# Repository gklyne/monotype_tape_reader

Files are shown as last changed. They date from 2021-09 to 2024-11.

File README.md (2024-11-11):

# monotype_tape_reader

Mechanical parts for reading paper tape created by Monotype keyboard.

To run the tape reader, plug the reader RPi in to the Mac USB port (middle port on RPi, not "Pwr in"), allow it a few seconds to start up, then SSH to the RPi:
    ssh graham@192.168.1.23  (p:a...?)
or:
    ssh graham@mcreader.local

(Before first time, from a Macbook, add an "RNDIS/Ethernet gadget" interface with DHCP network config, and no network address hiding.  This should then find the reader Raspberry Pi using mDNS (Bonjour).  Don't forget to turn off "Limit IP address tracking".  Thnen log in using "mcreader.local" option above.)

Once logged in, seek out and run `stepper-control.py`.

## TODO

### 2021-09-27: Revisions to first prototype

- [x] Stiffen camera support area of baseplate so it doesn't flex with weight of phone.  Propose to extend plate both sides of reader bar.

- [x] Camera support bracket:  make space for nuts on the threaded rod (move holes away from vertical side)

- [x] Camera support bracket: increase width of base.

- [x] positive location/keying for reader bar.

- [x] Increase M4 hole size

- [x] Arrangement to prevent phone holder rotating on bar.  Also improve phone positioning.

- [x] Countersink for winder crank screw; review crank design to ensure pulley groove is clear of turning crank

- [x] Option to remove winder so that tape can be loaded/unloaded.

- [x] tape tensioning arrangement.  Guides to wrap tape around reader bar?

- [x] slot in winder shaft for catching tape (?)  C-clip over shaft?

- [x] Clamp to attach reader mechanism to a solid baseplate.

- [x] Larger gaps and guide rods for reader bar

### 2022-08-19: revisions to Mk2

(see Journal/20220819-MC-journal-reader-mk2.md)

[x] Redesign the tape-path guides to use guide sprockets.

[x] Include a small raised inner hub on the support brackets for the tape spools.

[x] Make the tape spools wider (more excess over width of the tape)

[x] Use a spoked design for the tape spools (less plastic, print time and weight).

[x] Replace axle for tape spools with a plastic locking arrangement, so they are more easily separated to remove the tape.

[x] Redesign the tape clips to slip on and off the winder spools, and with a lip to stop them spinning

### 2022-10-02: revisions to Mk2.5

[x] Clip wider flange

[x] Storage clip more clearance, no break.  This to allow it to slide off.

[-] Stiffer baseplate (8 -> 12mm edge height?) (doesn't seem necessary?)

[x] Additional mount and foot for winder/stepper (front edge)

[x] Winder separate from reader bridge (drive belt stresses structure)

[x] Captive nut holders in baseplate (shortened overall length by 100cm)

[-] Make the baseplate wider (doesn't seem necessary?)

[x] Sprocket pins larger (why are they so small?)

### 2022-12-10: using stepper motor to driver spool

[x] Code options for stop, start, speed?

[x] Stiffen up stepper motor bracket and spool support

[x] Single piece side support and stepper bracket

[x] Larger stepper pulley for drive

[x] Sprocket guides wrap further around sprockets

### 2023-02-03: tweak design

[x] smaller stepper motor pulley (50mm -> 35mm) - should be less liable to stalling motor

[x] wider flanges on tape guide rollers, reduced tape width clearance - hopefully reducing tendency of tape to ride up on rollers.

[x] adjust to use nylock nuts for axle supports, to prevent the axles from tightening on the supports while processing a tape.

[x] increase height of guide sprocket pins, to try and reduce tendency for the tape to ride off the pins

[x] redesign spool clip

## 2023-02-16: reasonably successful recording (?)

[x] Try spool clip without support bridges

[x] Drive belt channel should be wider, U-profile.

[x] Balance feeder spool (handle makes it unbalanced)

[x] Shim for spool end, for more positive "click"

## 2023-02-20:

[x] Smaller stepper motor pulley

[x] Reader bridge add shades to reduce detection of outer EL wire

[x] Use dark colour plastic for reader bridge

[x] Redesign winder spools to use smaller shaft dia; 
    e.g. M4 using bolts rather than through-rod.
    This is to reduce friction when drawing the tape off the spool.

[x] Design arms to hold tape tensioner(s)

[x] Slow down default tape speed (2.5ms -> 3ms between steps)

[x] Check ordering of row data when multiple detected together

[x] Add video frame number to output data file

## 2023-02-20:

[x] Progressive slowing of stepper motor as reading proceeds.

## 2023-09-24:

Following [meeting with Dawn](Journal/20230924-more-reader-changes-needed.md).

[x] Wider slot for brighter EL wire (+0.2mm)

[x] Wider light baffles on EL bridge

[x] Drive belt tensioning arrangement

[x] More flexibility of camera positioning

[x] Make camera clamp screws easier to access

[x] Mount for Pi Zero and EL switch wire (and power supplies?)

## 2023-11-25

[x] Winder side clip not closed

[x] Hinge on motor mount is too close

[x] Extend curved slot towards motor body

[x] Extend tension adjustment link by 2-3mm

[x] Shorten & widen tension adjustment clamp/nut holder

[x] Reduce size of screw bulge on motor holder (radius by 1mm?)

[x] Wider spacer ridge on inside of winder holder side

## 2023-12-01

[x] Extend arm on winder holder side; shorten adjustment link.
    - still need to choose adjustment arm length
    - is this a good idea? Single link may be more rigid

[x] Adjuster link countersink one end only.  Other end uses cap head.

[x] Lower baffle (shade) on reader bridge

[x] Winder spool axis: use bearing or sleeving to avoid creep along the shaft thread
    - use spool design from free end, and add sleeves over M4 screw.
    - New clip holes need to be diameter of sleeve.
    - Use sleeve bearings on both spools to reduce drag.

[x] Shorter roller arm on take-up spool side?

[x] Small collection of tools to facilitate assembly/maintenance

## 2024-01-13

[x] Iterations on design of tape follower roller arm, to allow free movement of the tape

## 2024-02-21

[x] Increase overhang of bridge shade shells (+1mm inside and outside)

[x] Revert to smaller EL wire and smaller gap in bridge

[x] Redesign reader device to be more uniform with less wobble

[ ] 

## 2024-06-28

[x] Design tweaks while reprinting with PETG, following "meltdown" of original PLA print.  (Turns out the PLA can start sagging when left out in the sun.)

[x] Widen baseplate by 2mm to provide more clearance for the rollers/spools.

## To consider (2024-02-13)

[ ] Threshold detection coordinate extraction is a bottleneck -- can this be optimized?
    - see function 'find_frame_regions'
    - possible to detect and merge local overlaps before comparing all?
    - Or collapse row-runs of pixels into (min,max) groupings?

[ ] Shorter EL wire? 

[ ] Provide "output_log.txt" file to analyse algorithm behaviour details
    - region detection: num regions, region size, shape variations
    - trace detection: summarize contributing regions
    - row detection: initial and final candidates

[ ] Marker threshold setting is rather sensitive

[ ] Analyze threshold setting w.r.t. region area and shape variations; also number of regions detected.  Can threshold setting be adjusted automatically using this?   (See logging options above.)

## Shelved

[ ] Running calibration of data scale - maybe it's not truly linear (consistent hole 22 deviation).
    Consider low order polynomial, correction (quadratic?, cubic?)

[ ] Use battery supply for EL wire (less prone to brightness changes?)

[ ] Attach battery supply to reader rig

## Notes

### Notes: 2023-03-05

## Write-up notes

### Pipeline

Iterating the design

Aim to use software as much as possible, while keeping the hardware simple

Design involving iterative updates to both hardware and software

Initially: reader and video analysis

Then switch to 3 elements: hardware, stepper control s/w, video analysis

Basic mechanism and analysis worked fairly easily, but...

Dealing with noisy data, interactions between:
- better video analysis
- better hardware
- better tape motion control

Lots of learning:  more efficient use of OpenSCAD for evolving mechanical design; OpenCV for video analysis and generation, Raspberry Pi to control stepper motor, simple statistics-based algorithms for dealing with noisy data.

Each attempt to improve the decoding software can show up fundamental problems with the raw data, which are not reliably overcome by better processing (e.g. might confuse a human attempting to decode the data), thus giving rise to new hardware iterations.  Then each new hardware iteration and video recording can throw up new patterns of data noise to be handled by the decoding software, so there's a lot of iteration between hardware and software improvements.

Ambient lighting is a big factor in the quality of video obtained.

### Reader hardware

Initially simple hand crank from  spool to spool, drawing tape over EL wire

Tape guide hardware enhancements to reduce tape wear

Hardware enhancements to use less plastic when printing

Using code to describe hardware (CSG, OpenSCAD)

Building a component library (OpenSCAD)

Increase spool size to reduce tape speed variation beginning to end (pre-stepper)

Switched to stepper motor drive for better control of tape speed

Additional hardware (RPi, stepper controller, stepper motor) and software to control stepper

Added speed profile (to control software) as analysis had holes merging towards end of tape

Add tape follower rollers to help keep tape on guide sprockets, and absorb some slack

Add rod mounting plate extensions to leave for space for tape follower roller arms

Add drive belt tensioner to control slippage

Use smaller shafts and metal sleeve bearings for smoother tape movement

Experiment with wider, brighter EL wire, but this ended up with rows getting merged

Extra hardware for mounting RPi, and other bits, on reader frame

### Decoding software

Processing pipeline

Uses OpenCV to read recorded video, and to perform initial threshold detection

Initial processing draws inspiration from motion capture software implemented in 1980s

Pipeline applies conversion from (X,Y) coordinates in video to (Y,frame) coordinates for data decode.

Row detection uses RANSAC-inspired algorithm to identify row-aligned markers.

Also uses OpenCV to create synthesized video of analysis process, with original video and internal data from processing pipeline.

Data visualization has proved very important whole developing algorithm, especially for understanding the impact of noisy data and helping to identify algorithmic improvements.  Also helped to identify where hardware improvements were needed.

Have spent significant thought reflecting on how I, as a human observer, am easily seeing row data where the algorithm if failing.  This has led to changes in the structure of the pipeline; e.g. noticing that the sprocket holes are a very regular pattern, and introducing in-pipeline feedback to use detected sprocket holes to help discard spurious data in the earlier row-detection phase.

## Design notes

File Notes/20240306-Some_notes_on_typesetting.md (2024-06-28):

# Some_notes_on_typesetting.md

Some notes on the typesetting process

Clarice's diary was hand written in an exercise book during the period 1915-16.  This printed version has been produced using the Monotype system, the process for typesetting that would have been used in her lifetime.

The Monotype system consists of two machines: a keyboard and a caster which communicate by means of a spool of punched paper tape.  The keyboard produces the spool containing encoded text and layout information.  The caster reads the punched code and, line by line, produces pages of justified type cast from molten lead using a matrix.  The chosen typeface, in this case Bulmer 11pt, is determined by the matrix containing a grid of character moulds.

This entirely mechanical system revolutionised book production during the early 20th century.
The use of punched paper tape was an idea ahead of its time, which reappeared later in digital computers.
It was offset and digitised production processes built around these computers that were to eventually replace the Monotype system in the latter half of the century.

Monotype is a rare system that is now hard to find in use.  Stan Lane of Gloucester Typesetting Services has been using this process for over 40 years, and is now passing the mantle to Katie Beard of Rooksmoor Press.  Their knowledge and expertise are what has made production of this book possible.

....

_Dawn Cole is the keeper of the Clarice Alberta Spratling archive, and has been using its contents as inspiration for her creative practice as a conceptual artist since 2007._

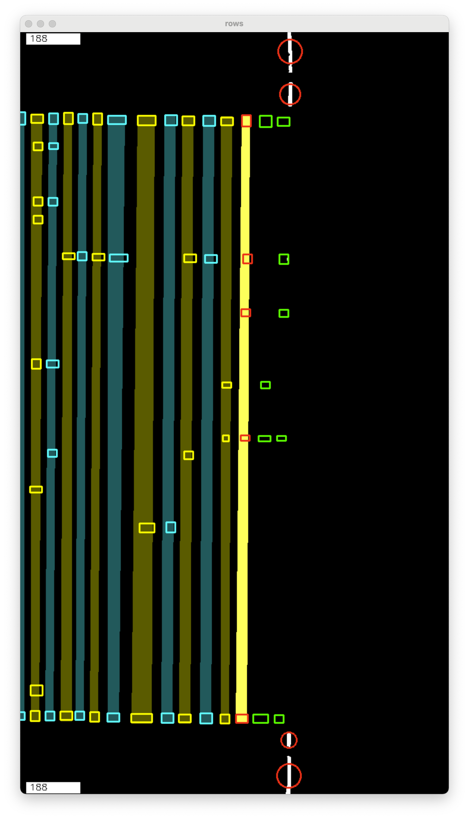
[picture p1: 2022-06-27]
Notes/DHOxSS-poster/20220523-MC-rows.png

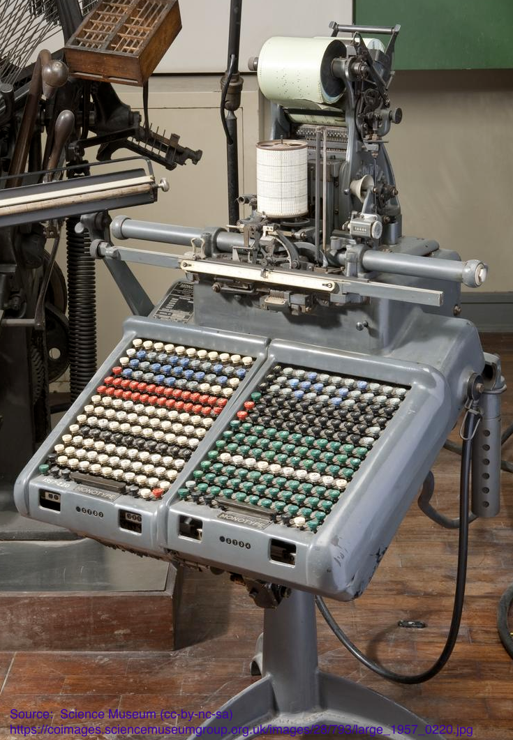
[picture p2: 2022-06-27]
Notes/DHOxSS-poster/20220519-monotype-keyboard.png

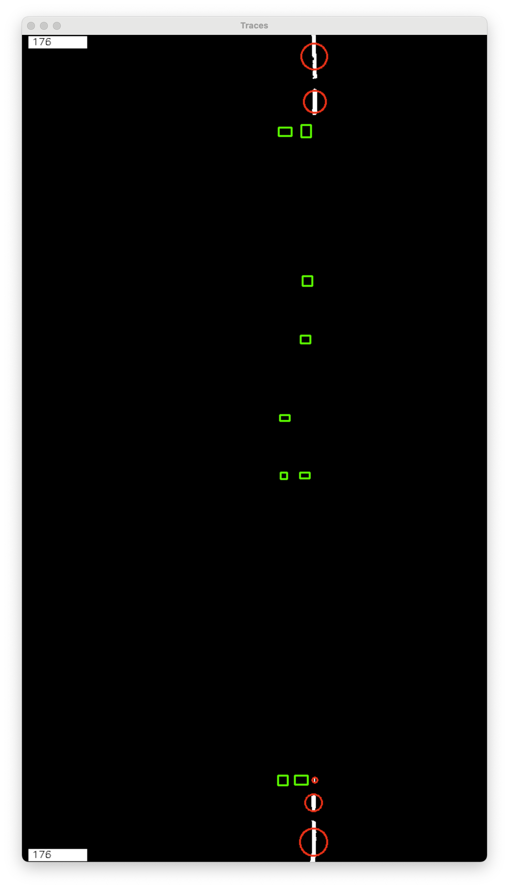
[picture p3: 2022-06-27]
Notes/DHOxSS-poster/20220523-MC-traces.png

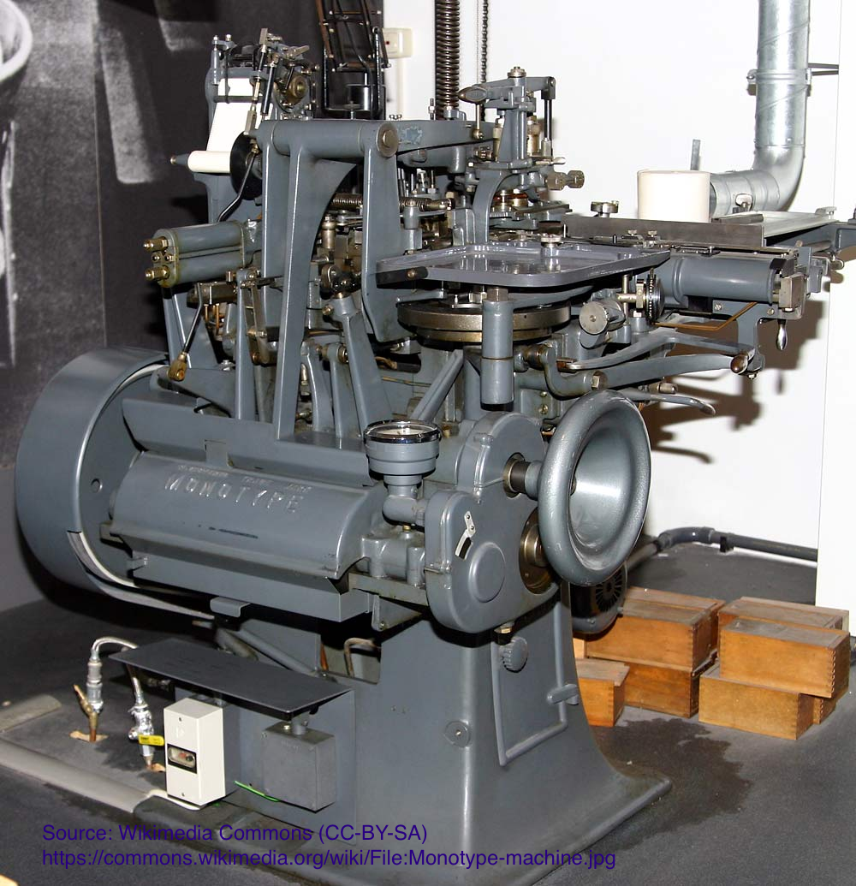
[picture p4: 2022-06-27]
Notes/DHOxSS-poster/20220519-monotype-caster.png

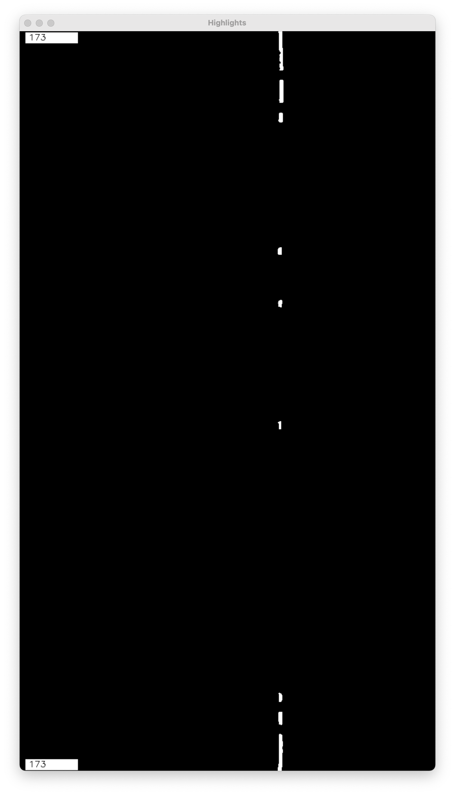
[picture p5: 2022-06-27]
Notes/DHOxSS-poster/20220523-MC-highlights.png

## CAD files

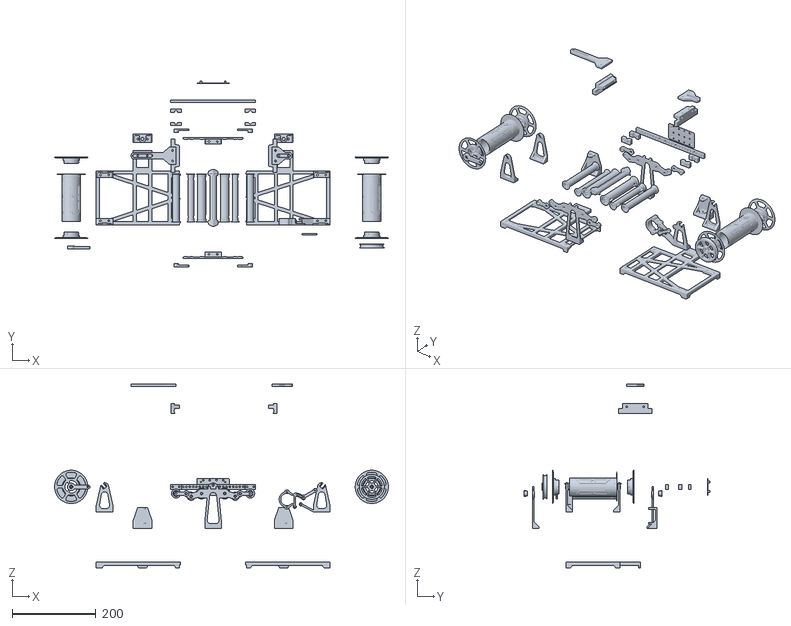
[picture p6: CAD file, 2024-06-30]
Monocaster-assembly-exploded.stl
800.0 x 444.5 x 440.0

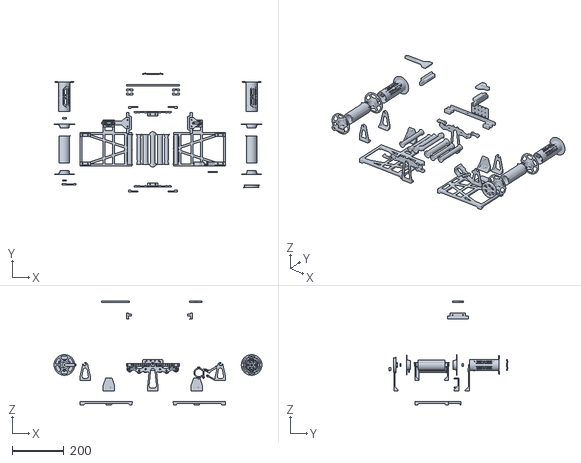
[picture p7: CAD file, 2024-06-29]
Monocaster-assembly.stl
800.0 x 459.5 x 400.0

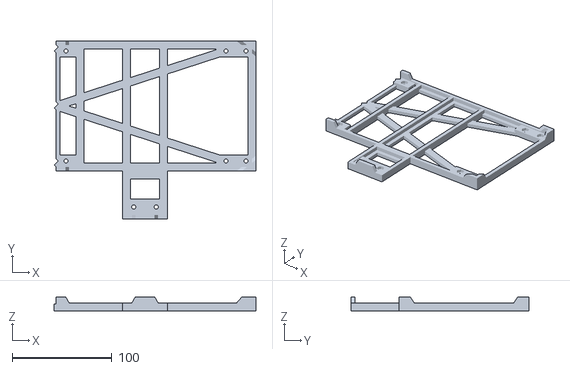
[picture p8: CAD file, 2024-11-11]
stl/reader_half_baseplate_2.stl
202.0 x 178.0 x 14.0

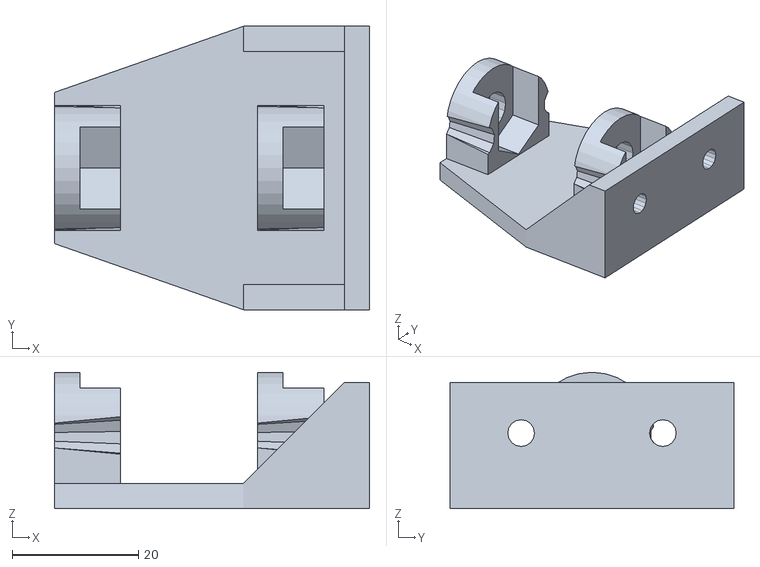
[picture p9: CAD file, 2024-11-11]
stl/phone_holder_rod_support.stl
50.0 x 45.0 x 21.6

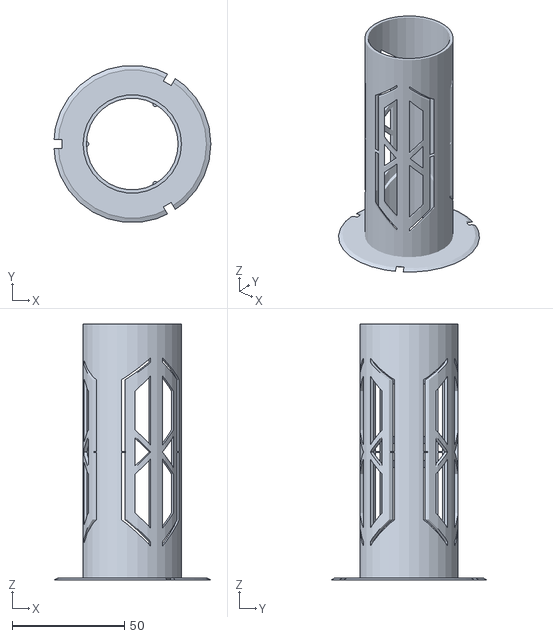
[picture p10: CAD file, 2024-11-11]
stl/spool_clip_closed.stl
69.8 x 69.6 x 113.9

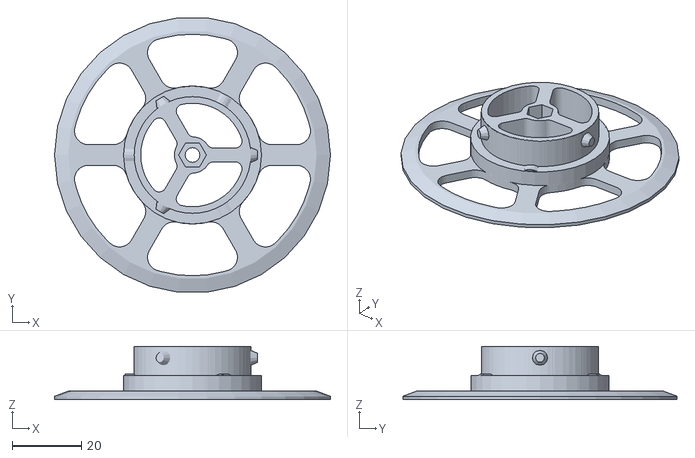
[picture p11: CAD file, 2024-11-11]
stl/spool_end.stl
80.0 x 79.6 x 15.5

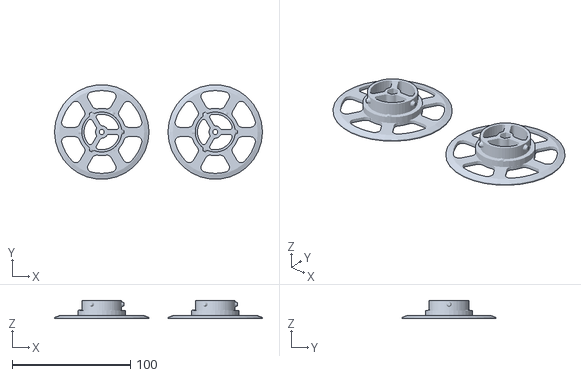
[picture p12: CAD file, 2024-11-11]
stl/spool_end-2off.stl
176.0 x 79.6 x 15.5

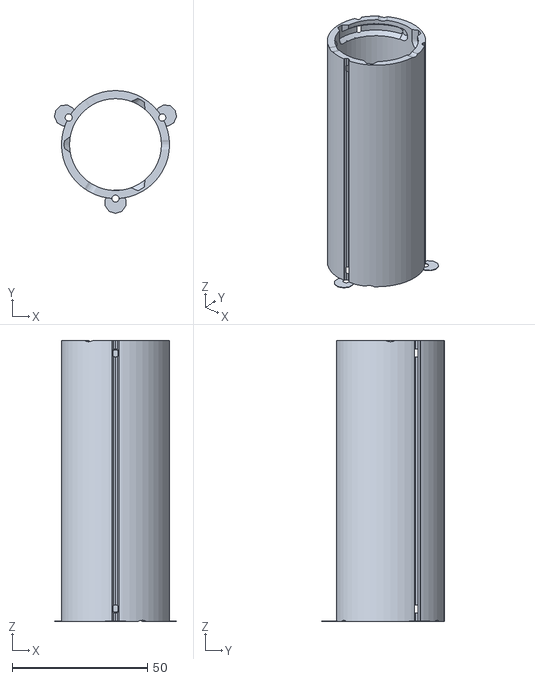
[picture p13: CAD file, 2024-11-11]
stl/spool_middle.stl
45.2 x 45.5 x 104.0

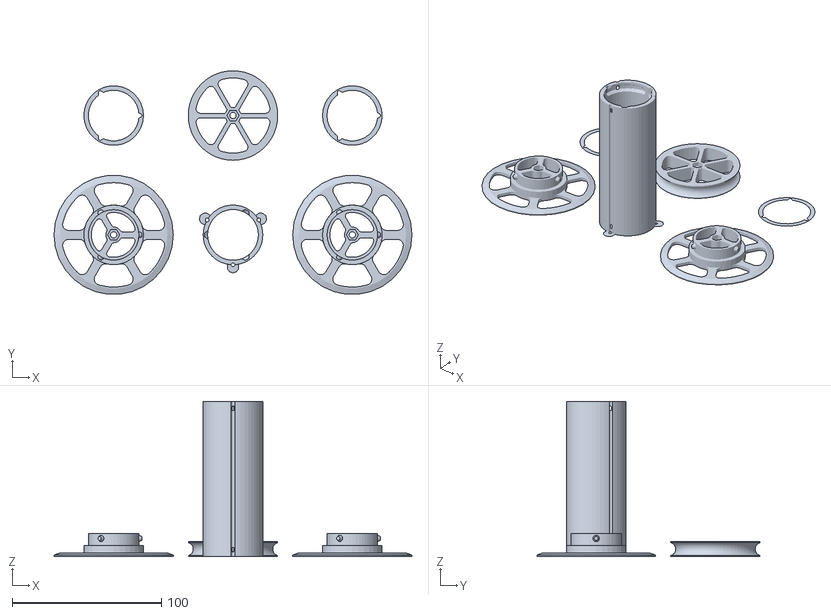
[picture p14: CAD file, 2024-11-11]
stl/spool_all_parts.stl
240.0 x 149.8 x 104.0

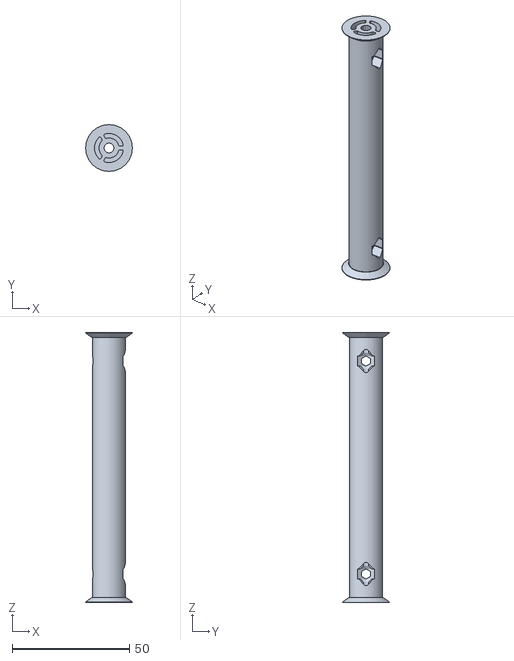
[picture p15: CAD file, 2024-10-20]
stl/roller_tape_guide.stl
20.0 x 20.0 x 115.0

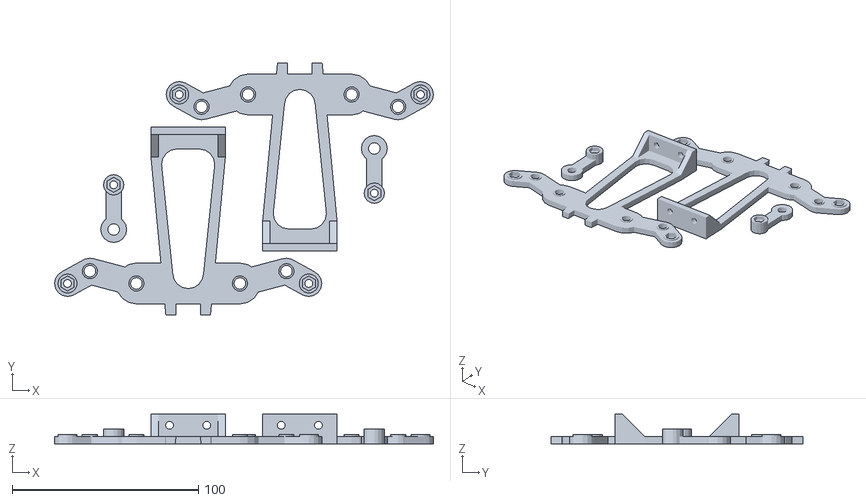
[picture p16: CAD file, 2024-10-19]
stl/reader-bridge-side-supports-and-follower-arms.stl
203.6 x 135.5 x 16.0

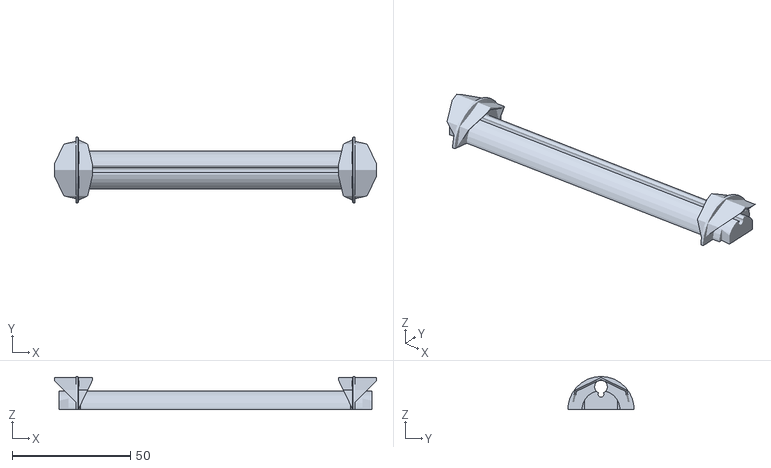
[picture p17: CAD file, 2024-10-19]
stl/tape_reader_bridge_dovetailed.stl
136.0 x 27.8 x 14.0

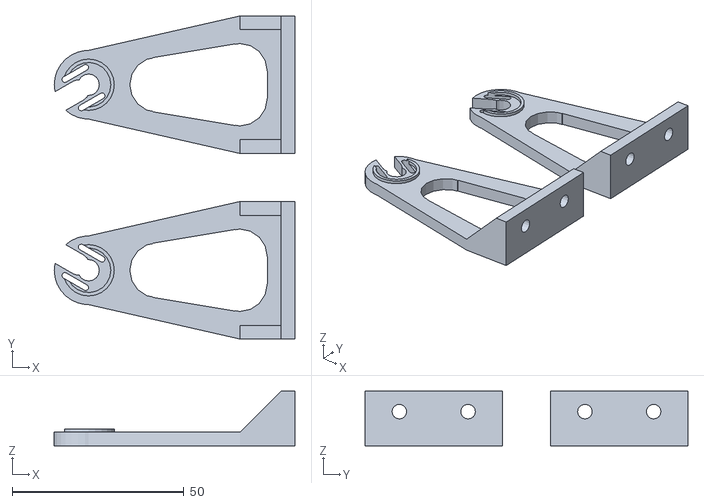
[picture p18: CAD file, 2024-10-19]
stl/spool_side_support_slotted-2off.stl
70.0 x 94.0 x 16.0

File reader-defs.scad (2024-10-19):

// Default dimensions

m_clearance = 0.25 ;        // Clearance for close-clearance holes
m2_5    = 2.5+m_clearance ; // Close clearance hole for M2.5 screw
m3      = 3+m_clearance ;   // Close clearance hole for M3 screw
m4      = 4+m_clearance ;   // Close clearance hole for M4 screw
m5      = 5+m_clearance ;   // Close clearance hole for M5 screw
m6      = 6+m_clearance ;   // Close clearance hole for M6 screw/sleeve
m8      = 8+m_clearance ;   // Close clearance hole for M8 screw/sleeve

m2_5_nut_af = 5.0 ;         // M2.5 nut a/f size
m2_5_nut_t  = 2.0 ;         // M2.5 nut thickness (for recess)
m2_5_csink  = m2_5*2 ;      // M2.5 countersink diameter

m3_nut_af    = 5.5 ;        // M3 nut a/f size
m3_nut_t     = 2.2 ;        // M3 nut thickness (for recess)
m3_hinge_dia = 8.0 ;        // M3 hinge knuckle diameter
m3_csink     = m3*2 ;       // M3 countersink diameter

m4_nut_af    = 7 ;          // M4 nut a/f size
m4_nut_t     = 3.1 ;        // M4 nut thickness (for recess)
m4_slimnut_t = 2.5 ;        // M4 slim nut thickness (for recess)
m4_nylock_t  = 4.3 ;        // M4 nylock nut thickness (for recess)
m4_csink     = m4*2 ;       // M4 countersink diameter
m4_washer_d  = 8.9 ;        // M4 washer diameter
m4_washer_t  = 0.9 ;        // M4 washer thickness

m8_nut_af    = 13 ;         // M8 nut a/f size
m8_nut_t     = 6.5 ;        // M8 nut thickness (for recess)
m8_slimnut_t = 4 ;          // M8 slim nut thickness (for recess)

// Monotype system parameters

// 159/50 = 3.18
// 285.5/90 = 3.172
mt_sprocket_pitch = 3.2 ;   // was: 159/50; paper was riding up on pins after about 20 holes
mt_sprocket_dia   = 1.6 ;   // was: 1.5
mt_sprocket_width = 104.3 ; // Between sprocket hole rows
mt_overall_width  = 110 ;   // Overall width of tape
mt_paper_tickness = 0.08 ;  // Thickness of paper tape

// Winder

small_shaft_d      = m4 ;           // Shaft diameter
small_shaft_nut_af = m4_nut_af ;    // Nut diameter across faces
small_shaft_nut_t  = m4_nut_t ;     // Nut thickness

// Spool shaft may be used with a sleeve to make up to "shaft_d"
spool_shaft_d      = m4 ;           // Shaft diameter in spool
spool_shaft_nut_af = m4_nut_af ;    // Nut diameter across faces
spool_shaft_nut_t  = m4_nut_t ;     // Nut thickness
spool_sleeve_d     = m6 ;           // Spool sleeve bearing diameter

// shaft_d      = small_shaft_d ;
// shaft_nut_af = small_shaft_nut_af ;
// shaft_nut_t  = small_shaft_nut_t ;

shaft_d      = m8 ;                 // Shaft diameter in carrier
shaft_nut_af = m8_nut_af ;          // Nut diameter across faces
shaft_nut_t  = m8_slimnut_t ;       // Nut thickness

// Spool dimensions
core_d = 40 ;           // Core diameter
bevel_d = 72 ;          // Bevel inner diameter
outer_d = 80 ;          // Spool outer diameter
crank_hub_d = 25 ;      // Diameter of crank hub
drive_pulley_d = 60 ;   // Diameter of drive pulley
drive_pulley_t = 10 ;   // Thickness of drive pulley
handle_hub_d = 10 ;     // Diameter of handle end of crank
handle_d = m4 ;         // Diameter of handle
base_fix_d = m4 ;       // Diameter of base fixing screw hole
sup_t = 4 ;             // Default thickness for side supports @@was side_t

crank_l = 40 ;          // Length of crank (between shaft and handle centres

crank_hub_t = 16 ;      // Thickness of crank hub
crank_arm_t = 6 ;       // Thickness of crank arm
crank_end_t = 8 ;       // Thickness of crank handle hub (at end of arm)

spool_side_t = 2.5 ;    // Thickness of carrier spool side
spool_side_rim_t = 1 ;  // Thickness of carrier spool side rim (bevelled)
spool_w_all = 114 ;     // Width of spool (overall between ends)
                        // base_w - 2*(read_side_t+read_extra_l) ;
spool_w_end = 5 ;       // Width of spool (to inside of end)
spool_w_plug = 8 ;      // Width of spool-end plug overlap
spool_w_mid = spool_w_all - 2*spool_w_end ;
                        // width of spool middle spacer


handle_nut_af = 7 ;     // Nut diameter across faces
handle_nut_t  = 3 ;     // Nut thickness

winder_side_h = 60 ;    // Height to centre of winder shaft
winder_side_w = 40 ;    // Width base of winder side support
winder_side_t = sup_t ; // Thickness of winder side support
winder_apex_d = 20 ;    // Diameter of apex of winder side support
winder_base_t = 16 ;    // Thickness at base of winder

motor_support_l = 35 ;  // Length of motor mount support arm
motor_support_a = 20 ;  // Angle of motor mount support arm
motor_swivel_l  = 35 ;  // Length of motor swivel link (to clear spool rim)

// Reader bridge

read_w = 16 ;           // Width of bridge
read_extra_l = 5 ;      // Extra length of reader bridge for guides and tie-down

read_h = 95 ;           // Height of reader bridge above base plate
read_side_t = sup_t ;   // Reader bridge side support thickness
read_side_base_t = 16 ; // Reader bridge side support thickness at base 
read_total_l     = spool_w_all + 2*(read_side_t + read_extra_l) ;
read_side_apex_w = 24 ;
read_side_apex_h = 6 ;  // Height of dovetail on sides
read_side_base_w = 40 ;
read_side_peg_d  = m4 ;

// See: module tape_reader_bridge_with_guides
read_groove_w = 2.5 ;    // EL wire groove width
                         // (bright wire is 2.6 dia; use ???)
                         // (regular wire is 2.25-2.3 dia;  use 2.5)

guide_w  = 28 ;         // Width of guide flange on bridge
guide_tc = 2 ;          // Guide thickness at core
guide_tr = 1 ;          // Guide thickness at rim
guide_tb = guide_tc-guide_tr ;  // Guide thickness of bevel
guide_eld = 5.5 ;       // EL wire threading hole diameter
guide_ist = 5 ;         // EL wire shade inner overhang thickness
guide_ost = (read_total_l-spool_w_all)/2+2 ; // EL wire shade outer overhang thickness

// Guide roller parameters (shape of rims each end)

guide_rim_1_extra_radius = 3 ;      // Rim bevel outer 
guide_rim_2_extra_radius = 0.25 ;   // Rim bevel inner
guide_rim_1_width        = 0.2 ;    // Rim end thickness
guide_rim_2_width        = 2 ;      // Rim bevel thickness 
guide_rim_overall_width  = mt_overall_width + 5 ;  // Each rim 2.2 + 0.6 tape clearance

// Guide sprocket diameter and positioning...
guide_sprocket_dia      = 22 ;
guide_sprocket_sep      = guide_sprocket_dia*1.8 + read_w ;
guide_sprocket_ht_off   = guide_sprocket_dia*0.5 ;

// Guide roller diameter and positioning...
guide_roller_outer_d        = 14 ;
guide_roller_centre_x       = guide_sprocket_ht_off*1.6 ;   // e.g. 1.6 for droop, 
                                                            // 1 for level, 0.7 for lift
guide_roller_centre_y       = 
    guide_sprocket_sep/2 + 
    guide_sprocket_dia*0.5 + guide_roller_outer_d*0.5 + 
    guide_rim_1_extra_radius*2 + 1 ;

// Guide follower positioning
guide_follower_pivot_x      = guide_sprocket_ht_off*1 ;     // e.g. 1.6 for droop, 
                                                            // 1 for level, 0.7 for lift
guide_follower_pivot_y      = guide_roller_centre_y + 12 ;

tape_follower_arm_l         = 40 ;          // Arm length between shaft centres
tape_follower_short_arm_l   = 24 ;          // Short arm length between shaft centres
tape_follower_elbow_l       = 10 ;          // Length from pivot to end of elbow


// Parts for holding phone camera

hold_side_l = 80 ;      // Length is side of holder
hold_side_h = 12 ;      // Height of side above base
hold_side_t1 = 8 ;      // Thickness of side at base
hold_side_t2 = 10 ;     // Thickness of side at top

hold_base_l1 = 60 ;     // Length of base near side
hold_base_l2 = 50 ;     // Length of base towards centre
hold_base_t = 8 ;       // Thickness of base (to accommodate hole)
hold_base_w = 20 ;      // Width of base piece
hold_base_offset = 4 ;  // Thickness of standoff for clamp nut clearance

hold_rail_p = 40 ;      // Distance between rail holes
hold_rail_d = m4 ;      // Diameter of rail holes

hold_fix_p   = 25 ;     // Distance between fixing holes
hold_fix_d   = m4 ;     // Diameter of fixing holes
hold_nut_t   = 3.1 ;    // Thickness of holder fixing nut
hold_nut_af  = 6.9 ;    // Size across faces of holder fixing nut recess (tight fit)
hold_fix_o_x = 20 ;     // X-offset from vertical rod to holder fixing holes
hold_fix_o_y = 0 ;      // Y-offset from vertical rod to centre between fixing holes

// Dimensions for phone holder-to-rod attachment plate

hold_fix_t = 6 ;        // Thickness of plate (Z)
hold_fix_w = 8 ;        // Width of plate to shoulder (X)
hold_fix_l = 80 ;       // Length of phone holder-to-rod fixing (Y)
hold_fix_rod_d = m8 ;   // Diameter of phone holder support rod
hold_fix_hub_d = 16 ;   // Diameter of phone holder support hub

hold_fix_plate_l = hold_fix_o_x + hold_fix_rod_d ;
hold_fix_plate_w = hold_fix_p + hold_fix_rod_d*2 ;

// Dimensions for long slot plate to prevent rotation of camera

hold_slot_o_x1 = 60 ;   // Start of anti-rotation slot
hold_slot_o_x2 = 100 ;  // end of anti-rotation slot

// Dimensions for short slot plate to allow sideways adjustment of camera
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

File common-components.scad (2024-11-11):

////////////////////////////////////////////////////////////////////////////////
// Common components
////////////////////////////////////////////////////////////////////////////////

delta = 0.01 ;
clearance = 0.1 ;

module triangle_plate(x1,y1,x2,y2,x3,y3,h) {
    // Trangular plate on X-Y plane
    //
    // x1 = X position of first apex
    // y1 = Y position of first apex
    // x2 = X position of second apex
    // y2 = Y position of second apex
    // x3 = X position of third apex
    // y3 = Y position of third apex
    // h  = height (thickness) of plate
    linear_extrude(height=h, center=false) {
        polygon(
            points=[
                [x1,y1],
                [x2,y2],
                [x3,y3],
                [x1,y1],
                ]
            ) ;
    }
}
////-triangle_plate(x1,y1,x2,y2,x3,y3,h) instance
// triangle_plate(-10,-10,-10,+10,10,5,5) ;

module rectangle_plate(x1,y1,x2,y2,h, scale=1) {
    // Rectangular plate on X-Y plane
    //
    // x1 = X position of first apex
    // y1 = Y position of first apex
    // x2 = X position of opposite apex
    // y2 = Y position of opposite apex
    // h  = height (thickness) of plate
    // scale = reduces X-Y coordinates towards top of plate (see linear_extrude)
    //
    linear_extrude(height=h, center=false, scale=scale) {
        polygon(
            points=[
                [x1,y1],
                [x2,y1],
                [x2,y2],
                [x1,y2],
                [x1,y1],
                ]
            ) ;
    }
}
////-rectangle_plate(x1,y1,x2,y2,h, scale=1) instance
// rectangle_plate(-10,-10,10,15,5) ;
// rectangle_plate(10,15,20,30,5, scale=0.5) ;

module lozenge(l,bevel_l,w,h) {
    // Lozenge object along Z axis: one point on origin, other on X-axis
    //
    // l       = overall length (between points)
    // bevel_l = length of sloping shoulder
    // w       = width of lozenge
    // h       = height of lozenge
    //
    linear_extrude(height=h, center=false) {
        polygon(
            points=[
                [0,        0],  
                [bevel_l,  w/2],
                [l-bevel_l,w/2],
                [l,        0],
                [l-bevel_l,-w/2],
                [bevel_l,  -w/2],
                ]
            ) ;
    }
}

module oval(x, d, h) {
    // Oval shape aligned on the X axis, with one end centred on the origin
    //
    // x  = X position of second centre of curvature
    // d  = width of oval, also diameter of curved ends
    // h  = height (thickness) of oval
    //
    cylinder(d=d, h=h, $fn=16) ;
    translate([x,0,0])
        cylinder(d=d, h=h, $fn=16) ;
    translate([x/2,0,h/2])
        cube(size=[x, d, h], center=true) ;
}

module oval_xy(x1, y1, x2, y2, d, h) {
    // Oval shape on the X-Y plane, with ends at the indicated positions
    //
    // x1 = X position of first centre of curvature
    // y1 = Y position of first centre of curvature
    // x2 = X position of second centre of curvature
    // y2 = Y position of second centre of curvature
    // d  = width of oval, also diameter of curved ends
    // h  = height (thickness) of oval
    //
    l = sqrt((x2-x1)^2+(y2-y1)^2) ;     // Length of oval (between radius centres)
    a = atan2(y2-y1,x2-x1) ;            // Angle of oval from X-axis
    translate([x1,y1,0]) {
        cylinder(d=d, h=h, $fn=16) ;
        rotate([0,0,a])
            translate([0,-d/2,0])
                cube(size=[l, d, h], center=false) ;
    }
    translate([x2,y2,0])
        cylinder(d=d, h=h, $fn=16) ;
}
////-oval_xy(x1, y1, x2, y2, d, h) instance
// oval_xy(-20,30,-60,-60,10,5) ;


module hub(d, h) {
    // Hub: cylinder with hole for fixing, on X-Y plane, centred on the origin
    //
    // d  = diameter of fixing hole
    // h  = height (thickness) of hub
    //
    difference() {
        cylinder(d=d*1.6, h=h, $fn=16) ;
        shaft_hole(d, h) ;
    }
}

module brace_xy(x1, y1, x2, y2, w, d1, d2, h) {
    // Brace with rounded ends with fixing holes
    //
    // x1 = X position of first fixing hole
    // y1 = Y position of first fixing hole
    // x2 = X position of second fixing hole
    // y2 = Y position of second fixing hole
    // w  = width of brace
    // d1 = diameter of fixing hubs
    // d2 = diameter of fixing holes
    // h  = height (thickness) of brace
    //
    l = sqrt((x2-x1)^2+(y2-y1)^2) ;     // Length of brace (between radius centres)
    a = atan2(y2-y1,x2-x1) ;            // Angle of brace from X-axis
    difference() {
        union() {
            translate([x1,y1,0]) {
                cylinder(d=d1, h=h, $fn=16) ;
                rotate([0,0,a])
                    translate([0,-w/2,0])
                        cube(size=[l, w, h], center=false) ;
            }
            translate([x2,y2,0])
                cylinder(d=d1, h=h, $fn=16) ;
        }
        translate([x1,y1,0]) shaft_hole(d2, h) ;
        translate([x2,y2,0]) shaft_hole(d2, h) ;
    }
}
////-brace_xy(x1, y1, x2, y2, w, d1, d2, h) instance
// brace_xy(-20,30,-60,-60,8,12,8,5) ;


module shaft_hole(d, l) {
    // Cutout for shaft hole diameter d and length l
    // Shaft axis on Z axis.
    //
    translate([0,0,-delta]) {
        cylinder(d=d, h=l+delta*2, $fn=16) ;
    };
}

module shaft_slot(x1, x2, y, d, h) {
    translate([x1,y,-delta])
        oval(x2-x1, d, h+2*delta) ;    
}

module rounded_triangle_plate(x1,y1,x2,y2,x3,y3,r,h) {
    // Trangular plate on X-Y plane with rounded corners
    //
    // x1 = X position of first corner (centre of radius)
    // y1 = Y position of first corner (centre of radius)
    // x2 = X position of second corner (centre of radius)
    // y2 = Y position of second corner (centre of radius)
    // x3 = X position of third corner (centre of radius)
    // y3 = Y position of third corner (centre of radius)
    // r  = radius of rounded corners
    // h  = height (thickness) of plate
    d = r*2 ;
    triangle_plate(x1,y1,x2,y2,x3,y3,h) ;
    oval_xy(x1,y1,x2,y2,d,h) ;
    oval_xy(x2,y2,x3,y3,d,h) ;
    oval_xy(x3,y3,x1,y1,d,h) ;
}
////-rounded_triangle_plate(x1,y1,x2,y2,x3,y3,r,h) instance
// rounded_triangle_plate(-20,-20, -10,+10, 10,5, 3,5) ;


module rounded_rectangle_plate(x1,y1,x2,y2,r,h) {
    // Rectangular plate on X-Y plane with rounded corners
    //
    // x1 = X position of first corner (centre of radius)
    // y1 = Y position of first corner (centre of radius)
    // x2 = X position of opposite corner (centre of radius)
    // y2 = Y position of opposite corner (centre of radius)
    // r  = radius of rounded corners
    // h  = height (thickness) of plate
    d = r*2 ;
    rectangle_plate(x1,y1,x2,y2,h) ;
    oval_xy(x1,y1,x1,y2,d,h) ;
    oval_xy(x1,y2,x2,y2,d,h) ;
    oval_xy(x2,y2,x2,y1,d,h) ;
    oval_xy(x2,y1,x1,y1,d,h) ;
}
////-rounded_rectangle_plate(x1,y1,x2,y2,r,h) instance
// rounded_rectangle_plate(-10,-10, 10,15, 3,5) ;

module torus(tr, rr) {
    // Torus centred on origin.
    //
    // tr       torus radius (centre of ring to centre of rim)
    // rr       rim radius
    //
    rotate_extrude($fn=64) {
        translate([tr,0,0])
            circle(r=rr, $fn=32) ;
    }
}
////-torus(tr, rr) instance
// torus(20, 3);

// Triangular prism on X-Y plane, centred and aligned on X-axis, one end at origin
//
// w  = width of base of prism
// h  = height of apex
// l  = length of prism
//
module triangular_prism(w,h,l) {
    rotate([0,90,0])
        linear_extrude(height=l)
            polygon(
                points=[
                    [0,  -w/2], 
                    [0,  +w/2],
                    [-h, 0],
                    ],
                paths=[[0,1,2,0]]
                ) ;
}

// Trapezoidal prism on X-Y plane, centred and aligned on X-axis, one end at origin
//
// w1 = width of base of prism
// w2 = width at top of prism
// h  = height of top of prism
// l  = length of prism
//
module trapezoidal_prism(w1,w2,h,l) {
    rotate([0,90,0])
        linear_extrude(height=l)
            polygon(
                points=[
                    [0,  -w1/2], 
                    [0,  +w1/2],
                    [-h, -w2/2],
                    [-h, +w2/2],
                    ],
                paths=[[0,2,3,1,0]]
                ) ;
}

// Platform to fit inside vertically-printed cylinder, with angled infill below.
// Top of platform lies in X-Y plane, centred on origin.
//
// r  = radius of platform
// h  = height of platform infill
//
module circular_platform(r,h) {
    translate([0,0,-h]) {
        difference() {
            cylinder(r=r+delta, h=h) ;
            translate([0, 0,-delta])
                cylinder(r1=r+delta, r2=0, h=r*0.8) ;  
        }
    }
}
////-circular_platform(r,h) instance
// Instance of circular_platform (With cutaway to reveal angle of support.)
// difference() 
//    { circular_platform(10,8) ; translate([0,0,-10]) cube(size=[20,20,20]) ; }
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

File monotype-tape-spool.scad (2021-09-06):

    
shaft_d = 8 ;           // Shaft diameter
core_d = 18 ;           // Core diameter
bevel_d = 30 ;          // Bevel inner diameter
outer_d = 40 ;          // Spool outer diameter
crank_hub_d = 25 ;      // Diameter of crank hub
handle_hub_d = 10 ;     // Diameter of handle end of crank
handle_d = 4 ;          // Diameter of handle
base_fix_d = 4 ;        // Diameter of base fixing screw hole

crank_l = 40 ;          // Length of crank (between shaft and handle centres

side_t = 4 ;            // Thickness of spool side
side_rim_t = 2 ;        // Thickness of spool side rim (beveled)
crank_hub_t = 6 ;       // Thickness of crank hub
crank_arm_t = 4 ;       // Thickness of crank arm

spool_w_all = 112 ;     // Width of spool (overall between ends)
spool_w_end = 20 ;      // Width of spool (to inside of end)
spool_w_mid = spool_w_all - 2*spool_w_end ;
                        // width of spool middle spacer

shaft_nut_af = 13 ;     // Nut diameter across faces
shaft_nut_t  = 4 ;      // Nut thickness

handle_nut_af = 7 ;     // Nut diameter across faces
handle_nut_t  = 3 ;     // Nut thickness

winder_side_h = 50 ;    // Height to centre of winder shaft
winder_side_w = 40 ;    // Width base of winder side support
winder_side_t = 4 ;     // Thickness of winder side support
winder_apex_d = 16 ;    // Radius of apex of winder side support
winder_base_t = 16 ;    // Thickness at base of winder

delta = 0.1 ;           // Small value to force overlap
spacing = outer_d+10 ;  // Object spacingh (pitch)
part_gap = 10 ;         // Spacing between exploded assembly parts

// Utilities

module shaft_hole(d, l) {
        translate([0,0,-delta]) {
            cylinder(d=d, h=l+delta*2) ;
        };
}
  
module nut_recess(af, t)  {
    od = af * 2 / sqrt(3) ; // Diameter
    translate([0,0,-delta]) {
        cylinder(d=od, h=t+delta, $fn=6) ;
    }
}

module web_base(w_x, w_y, w_t) {
    // Web with corner on origin, extending along +ve X and Y axes
    // Slight negative x- and y- overlap forces merge with existing shape
    linear_extrude(height=w_t, center=true) {
        polygon(
            points=[
                [-delta, -delta], [-delta, w_y],
                [0, w_y], [w_x, 0],
                [w_x, 0], [w_x, -delta],
                ],
            paths=[[0,1,2,3,4,5,0]]
            ) ;
    }
}

module web_oriented(w_x, w_y, w_t) {
    // Web with corner on origin, extending along +ve or -ve X and Y axes
    if (w_x >= 0)
        {
        if (w_y >= 0)
            {
                web_base(w_x, w_y, w_t) ;
            }
        else // w_y < 0
            {
                // flip through x-z plane: reverse y-axis
                mirror(v=[0,1,0]) web_base(w_x, -w_y, w_t) ;
            }
        }
    else // w_x < 0
        {
        if (w_y >= 0)
            {
                // flip through y-z plane: reverse x-axis
                mirror(v=[1,0,0]) web_base(-w_x, w_y, w_t) ;
            }
        else // w_y < 0
            {
                // flip through x-z and y-z planes: reverse x- and y- axes
                mirror(v=[1,1,0]) web_base(-w_x, -w_y, w_t) ;
            }
        }
 }

module web_xz(x, y, z, w_x, w_z, w_t) {
    // Web in X-Z plane, outer corner at x, y, z
    if (y >= 0) {
        // Rotate around X maps Y to Z, Z to -Y (???)
        translate([x, y - w_t/2, z]) rotate([90,0,0]) web_oriented(w_x, w_z, w_t) ;
    }
    else { // y < 0
        translate([x, y + w_t/2, z]) rotate([90,0,0]) web_oriented(w_x, w_z, w_t) ;
    }
}

// Spool

module spool_edge(shaft_d, core_d, bevel_d, outer_d, side_t, side_rim_t) {
    // Edge in X-Y plane with centre of outer face at (0,0,0)
    union() {
        cylinder(d1=outer_d, d2=outer_d, h=side_rim_t) ;
        translate([0,0,side_rim_t]) {
            cylinder(d1=outer_d, d2=bevel_d, h=side_t-side_rim_t) ;
        } ;
    } ;
}

module pulley(d,t) {
    cylinder(d1=d, d2=d-t, h=t/2+delta) ;
    translate([0,0,t/2])
        cylinder(d1=d-t, d2=d, h=t/2+delta) ;    
}


module spool_core(d_core, w_core) {
    cylinder(d=d_core, h=w_core) ;
}

module half_spool(shaft_d, core_d, bevel_d, outer_d, side_t, side_rim_t, w_spool_end) {
    difference() {
        union() {
            spool_edge(
                shaft_d=shaft_d, core_d=core_d, bevel_d=bevel_d, outer_d=outer_d, 
                side_t=side_t, side_rim_t=side_rim_t
            );
            spool_core(d_core=core_d, w_core=w_spool_end+side_t);
        } ;
        union() {
            shaft_hole(d=shaft_d, l=w_spool_end+side_t) ;
            nut_recess(af=shaft_nut_af, t=shaft_nut_t) ;
        } ;
    }
} ;

module spool_spacer(shaft_d, core_d, w_spacer, w_spool_end) {
    difference() {
        union() {
            spool_core(d_core=core_d, w_core=spool_w_mid);
        } ;
        union() {
            shaft_hole(d=shaft_d, l=spool_w_mid) ;
        } ;
    }
} ;
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

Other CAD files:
stl/reader_half_baseplate_1.stl
reader-assembly.scad
reader-baseplate.scad
reader-bridge.scad
reader-camholder.scad
reader-common.scad
reader-electronics_mounting.scad
reader-tools.scad
reader-winder.scad
reader_baseplate.scad

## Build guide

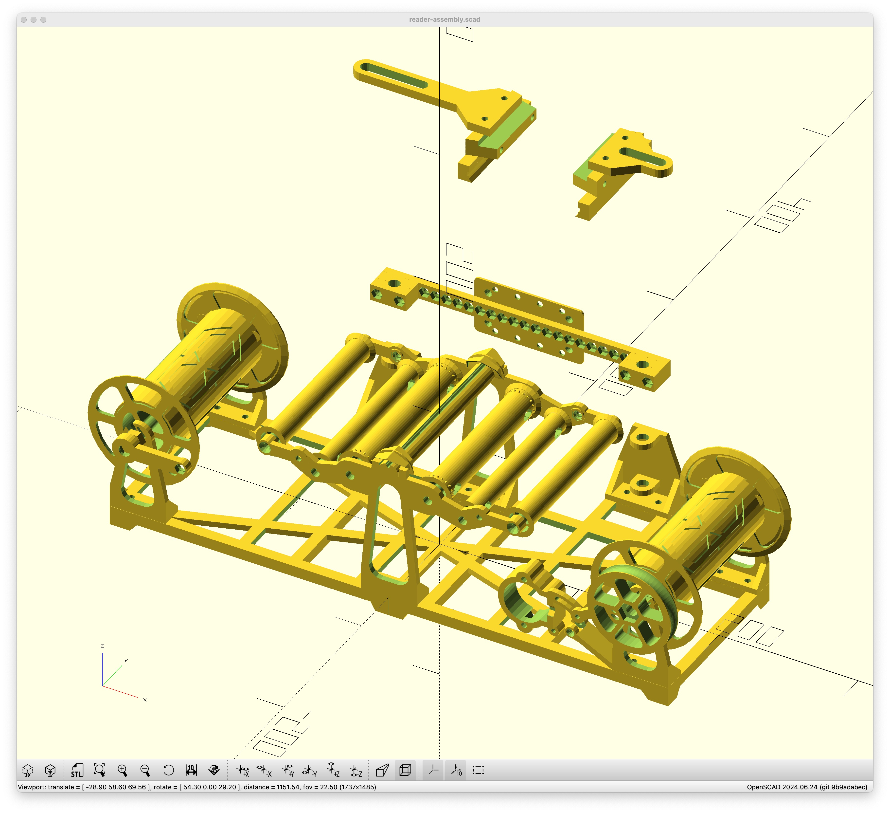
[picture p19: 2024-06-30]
Monocaster-assembly.jpg

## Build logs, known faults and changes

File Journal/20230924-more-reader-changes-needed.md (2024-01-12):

<!-- 20230924-more-reader-changes-needed.md -->

I met up with Dawn on a visit to Gravesend and Margate, with the intention of recording one or two videos of the Monotype tapes from typesetting Clarice's actual diary.  It didn't go smoothly, but we learned a few important lessons.

## Meeting in Gravesend 4th Portal

We had hoped to get a recording of the first of the diary tapes in St Andrews Chapel, Gravesend, then home of the 4th Portal.  The intention was that John (McK) could record this for posterity.  Unfortunately, we were distracted by other things happening in the chapel, and in the general confusion I forgot how to get the drive control software working, so in the end we didn't manage any recordings.  But I did eventually get the drive control software working, and added some notes to remind my future self what I need to do.

So Dawn and I agreed to meet up in Margate the next day and try again.

## Meeting in Margate

We spent some time getting the reader drive control software installed on Dawn's laptop, with the intention that I could leave the reader hardware with her to continue the recording process.  In the event, we weren't able to get a suitable recording, and some redesigns to the tape reader have been identified.

1. The drive belt that draws the tape through the reader was slipping, making it difficult to get a reasonably consistent speed of the tape across the read head.

2. The room environment in which we tried to record the tape was brighter than I had used previously.  We manually reduced the aperture when recording the video, but there was insufficient constrast to detect the tape holes.

3. Dawn's phone camera defaults to 4K @ 30fps.  Trying to process rthe video using OpenCV software proved to be extremely slow.

### Tape reader design

We need some way to tension the reader drive belt so that it doesn't slip.  Two possibilities come to mind:

(a) change the motor mounting to allow the motor to swing closer or further from the driven pulley, then locked in place, so that the position of the drive pulley can be adjusted.  This is similar to a common tensioning arrangement for automotive alternator drive belts.

(b) use a sprung or lockable follower pulley.  This would also allow the drive belt to be wrapped further around the driving and driven pulleys.

Also worth revisiting is to consider if the tape path friction can be further reduced.  Much of the friction now is from the tape path over the read head, so there may not be so much that is easily doable here.

Done ~2023-12.

### Video contrast for hole detection

Options here include:

(a) Use a darker ambient environment for recording the videos,

(b) See if the light source can be any brighter (I've just ordered some ostensibly brighter EL wire with a USB power supply - this may require the width of the reader bridge slot to be increased).  Done ~2023-12.

(c) Create an enclosure to shade the reader from ambient light.

@@@ TODO - test new EL wirer

### Video processing

I think lessons to be learned here are:

(a) Do not mess around with the video exposure, but rather allow the camera to set its own exposure level.  Focus instead in creating an environment that allows the camera to do its best.

(b) Stick to 1080P video resolution (or less):  the decoding process doesn't need, and cannot benefit from higher resolutions.  Faster frame rates may be helpful, as we do sometimes see tape rows missed because the gaps aren't sampled if the tape jerks forwards.

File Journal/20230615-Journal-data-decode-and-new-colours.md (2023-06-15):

<!-- 20230615-Journal-data-decode-and-new-colours.md -->

The previous journal post focused on improvements to the reader hardware and software over the preceding year.  This post focuses on some new developments in the software, many as a result of a meeting with Dawn.

## Revised colours for analysis pipeline visualization

The colours originally used for the video analysis pipeline visualization were chosen arbitrarily, with the only concern being that they were sufficiently visible to support pipeline diagnostic activities.  So rather lacking in aesthetic qualities.

Observers have commented that the visualization may itself be an(other) artistic output of the project.  As such it seems appropriate to include aesthetic and artistic considerations in the choice of colours, and how they might relate to the broader context of the Monotype Compositions project.

Dawn and I held a meeting in early June 2023, during which Dawn surfaced the role of colour in Clarice's diary.  While there are relatively few explicit references to colour, there are plenty of contextual references with associations to colours that would have been in use:  notably, the Red Cross, colours used in armed forces and medical uniforms.  Where possible, Dawn located archive photos of these items of the web, and took digital colour samples from them.  These were used to create a [mock-up palette of colours](./Decoder-colours.png) corresponding to the different functional elements of the analysis pipeline visualization.

<!--
![Mock-up of video analysis pipeline colours based on references in Clarice's diary](./Decoder-colours.png "Mock-up of video analysis pipeline colours")
-->

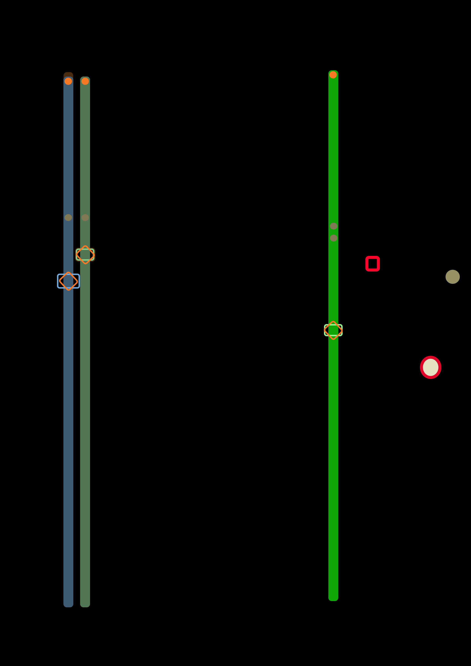
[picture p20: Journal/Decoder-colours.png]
Mock-up of video analysis pipeline colours based on references in Clarice's diary Mock-up of video analysis pipeline colours


Subsequently, I refactored the video analysis code to separate out the colour definitions, and used colours from the mock-up when generating the video.  These colours can be seen in the most recent video from processing the diary introduction page (`20230416-IMG_3082-intro-output_3.m4v`).

The colour table used is:

    # Colours linked to Clarice's diary
    COLOUR_MARKER           = Colour_val(R=90,  G=88,  B=76)    # Bright pixels (white)
    COLOUR_CENTROID         = Colour_val(R=80,  G=17,  B=19)    # Region centroid (red)
    COLOUR_FREE_TRACE       = Colour_val(R=90,  G=20,  B=20)    # Trace not allocated to row (green)
    
    COLOUR_NEW_BORDER       = Colour_val(R=60,  G=96,  B=57)    # Light green (Unused?)
    COLOUR_NEW1_ROW_FILL    = Colour_val(R=6,   G=65,  B=5)     # Odd rows: Neutral green
    COLOUR_NEW1_ROW_TRACE   = Colour_val(R=60,  G=96,  B=57)    # Odd rows: Bright green
    COLOUR_NEW2_ROW_FILL    = Colour_val(R=6,   G=65,  B=52)    # Even rows: Neutral green
    COLOUR_NEW2_ROW_TRACE   = Colour_val(R=60,  G=96,  B=57)    # Even rows: Bright green
    
    COLOUR_OLD_BORDER       = Colour_val(R=100, G=100, B=100)   # White (Unused?)
    COLOUR_OLD1_ROW_FILL    = Colour_val(R=25,  G=36,  B=45)    # Dull blue
    COLOUR_OLD1_ROW_TRACE   = Colour_val(R=45,  G=67,  B=87)    # Medium/bright blue
    COLOUR_OLD2_ROW_FILL    = Colour_val(R=33,  G=47,  B=33)    # Dull green
    COLOUR_OLD2_ROW_TRACE   = Colour_val(R=55,  G=80,  B=55)    # Medium/bright green
    
    COLOUR_SPROCKET         = Colour_val(R=97,  G=47,  B=14)    # Orange
    COLOUR_HOLE             = Colour_val(R=97,  G=47,  B=14)    # Orange
    COLOUR_HOLE_POS         = Colour_val(R=50,  G=50,  B=33)    # Dull olive
    COLOUR_HOLE_LABELS      = Colour_val(R=60,  G=60,  B=40)    # Light grey

(It occurred to me subsequently that the colours might also be interpreted as reflecting more gruesome aspects of the context that Clarice was dealing with: the white marker a flash of munitions, the red circle an initial injury, the red traces the resulting wounding and bloodshed, subsequent rows representing a process of putting the pieces back together into a more-or-less functioning person, and some that don't survive the wounding, and just die.)

## Monotype data decoding

Previous iterations of the analysis software have focused on the raw data on the tape, the presence or absence of punched holes and where they occur.  For this purpose, it was sufficient to simply number the rows `0` to `30` (counting from zero being a computer programming thing).

But now we have the data, it's natural to ask what it means, particularly in terms of its relationship to the printed diary.  The Monotype system assigns a code to each hole position across the width of the tape (which I refer to as columns).  Most of these codes relate to a row- or column position in the type matrix used (see below), and two others are related to spacing and end-of-line information.

<!--
![Monotype Bulmer font: keyboard arrangement and caster matrix layout](./Bulmer-monotype-DJI_20210721_120103_836.jpg)
-->

Monotype Bulmer font: keyboard arrangement and caster matrix layout Monotype Bulmer font details

The decoding software has been enhanced to show the Monotype column labels, both in the video and in the output data.  Further, the output data created includes indication of the corresponding character (where possible) that would be printed when using the Monotype Bulmer 469 matrix layout, this being used for typesetting and printing Clarice's diary.  Here is a short excerpt from the data decoded from the diary introduction:

    row 3000: frame 20732, data | -------O-- ---------- --O------- - |  (G,7       )  o
    row 3001: frame 20739, data | -------O-- --------O- ---------- - |  (G,3       )  r
    row 3002: frame 20745, data | ------O--- -------O-- ---------- - |  (H,2       )  t
    row 3003: frame 20752, data | -------O-- ---------- ---O------ - |  (G,8       )  n
    row 3004: frame 20758, data | ---------- O-------O- ---------- - |  (E,3       )  I
    row 3005: frame 20764, data | ---------- O------O-- ---------- - |  (E,2       )  -
    row 3006: frame 20770, data | ---------- O------O-- ---------- - |  (E,2       )  -
    row 3007: frame 20777, data | ---------- ---O------ ------O--- - |  (C,11      )  E
    row 3008: frame 20784, data | --------O- ---------- O--------- - |  (F,5       )  S
    row 3009: frame 20791, data | ---------- -O-------- -------O-- - |  (D,12      )  R
    row 3010: frame 20798, data | ------O--- ---------- --------O- - |  (H,13      )  U
    row 3011: frame 20805, data | --------O- ---------- --------O- - |  (F,13      )  N
    row 3012: frame 20811, data | -------O-- -------O-- ---------- - |  (G,2       )  
    row 3013: frame 20817, data | ---------- ---O------ --------O- - |  (C,13      )  D
    row 3014: frame 20824, data | ---------- O--------- -------O-- - |  (E,12      )  A
    row 3015: frame 20830, data | ---------- ----O----- -------O-- - |  (B,12      )  V

The data shows a tape row number, a corresponding video frame number (useful for cross-referencing the generated visualization video), a visual pattern of holes punched in that row, labels for the punched holes, and finally an indication of the corresponding character.  Note that the tape is read in a reverse direction, from the end to the start of the typeset text, so the actual decoded characters in the data would read from the bottom upwards.

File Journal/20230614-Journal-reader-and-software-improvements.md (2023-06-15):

<!--20230614-Journal-reader-and-software-improvements.md -->

It's been several months since my last journal entry.  Progress since then has been slow but reasonably steady. There have been numerous improvements to the tape reader hardware and software.

At this stage, I am regarding the reader and decoding software to be substantially complete, though there are still possible improvements that could be made.  In practice, I think the errors are few enough that they can be corrected by hand in the output data when discovered (the output file being a text file with frame numbers that can be cross-referenced with the video data, and which is easily modified using a text editor).  There is a separate "errors" file that indicates areas where possible inconsistencies have been detected, and which can be used in a manual review process.

The overall process of recording and decoding a tape can be rather sensitive to lighting conditions when the recording is made.  I have found that making the recordings at night in a room with low background light levels yields the best results, providing greater visual contract between the EL wire and the rest of the tape. I also need to avoid having light sources that may give rise to reflections from parts of the reader that are in view of the recording camera.

## Tape reader Mk3

A number of planned improvements to the tape reader hardware were identified in the last journal entry.  These have now all been implemented.  In summary, they are:

1. Use idler sprockets to guide the tape by its sprocket holes, reducing sliding contact with the edges of the tape and consequent tape damage.  

2. Longer tape spools, with more clearance of the tape width, so that the rims serve primarily to protect the tape, not to guide it.

3. Use a 3-spoked design for the tape spools to reduce the amount of plastic used in their manufacture, and also to make them lighter.

4. Include a small raised inner hub on the support brackets for the tape spools, reducing friction when drawing thye tape.

5. Shorten the tape path.  

6. Redesign the tape clips to slip on and off the winder spools.

A big additional change is to use a stepper motor rather than the hand-crank to draw tape over read head.  This allows for very much more even tape speed, and ultimately to maintain a more constant read speed by slowing down the motor as more tape is wound onto the take-up spool.  The motor is controlled by a Raspberry Pi with a stepper controller controller "hat", and a small custom program that provides signals to advance the motor at a desired rate.  The software is a command-line utility, run via an SSH remote terminal login to the Raspberry Pi, and provides a small number of simple interactive options for stopping, starting and varying the speed of the motor.  The software is in directory `winder-stepper-software` within the same GitHub repository as the 3D designs for the tape reader.  I'm currently using a Raspberry Pi 3, but the functionality can almost certainly be provided with a smaller (and cheaper) Raspberry Pi Zero.

Further changes to the design include:

1. Tape spool holder brackets redesign to also hold the stepper motor.  This avoids the drive belt tension causing the baseplate to flex and distort.

2. Tape spool redesign so that it can be easily separated to slide on a tape carrier/clip, and larger diameter to reduce proportional change in diameter as tape is wound on.

3. Add tape guide rollers that also help to maintain even tape tension and guide tape onto sprockets, and a push-on crank for rewinding tape (the fixed crank was creating uneven resistance when drawing tape over read head).

4. Redesigned clamp for holding a phone without fouling side-buttons (on an iPhone 11), and added extension plate so the camera holder vertical supports are further away from the tape path.

5. Various smaller design changes for more reliable printing, using less plastic, and easier assembly of the reader from its component parts.

An additional to the reader design is an alternate bridge, that clips into the same supports as the regular bridge, to help Dawn with manual decoding of Monotype tapes.  More details of all the changes can be seen in the [GitHub commit history](https://github.com/gklyne/monotype_tape_reader/commits/main).  

## Decoding software improvements

In parallel with the changes to the reader hardware, the video decoding software has been improved.  The most recent video of the introduction page was analyzed with just 8 inconsistencies detected, none of which led to discernable errors in the decoded data.

Details of the changes made can be found in the [GitHub commit history](https://github.com/gklyne/opencv-video-data-extraction/commits/main).

The key improvements made are through addition of sprocket hole tracking.  These changes were inspired by reflecting that when manually decoding data from the video, I would be using the row of sprocket holes as a guide to where the relevant data was to be found.  So, by tracking the sprocket holes separately, I aim to allow the software to be so guided, while still allowing for some spurious side-to-side and skewing movement of the tape, and especially variations in tape speed.  There is a potential sensitivity on initial detection of the sprocket holes (i.e. lacking data from previous frames), but in practice the tape lead-in with only sprocket holes, and relatively little "noise" in the initial frames, means this has not been a problem.  Subsequently, by excluding all trace data that lies clearly outside the tracked sprocket holes, several cases of spurious row data detected have been eliminated.

Other changes are improve trace detection, reduce spurious breaking up of traces due to missing, general tuning of various analysis parameters, and refactoring of the row detection logic.

Remaining problems include:

1. Occasional failure to detect "blank" -- i.e. rows with only sprocket holes.  This doesn't impact decoded typesetting data, but may affect the way we generate sound from the data.

2. Occasional failure to detect sprocket holes, though so far this hasn't resulted in any apparent errors in the decoded data.

3. Occasional multiple-detection of holes; this appears to be caused when the illuminated hole brightness is close to the hole detection threshold, or by an internal wire in the EL wire used appearing to split up the hole into multiple regions.

4. Missing data if the tape momentarily moves faster than the overall rate at which it is being drawn.  This is partly down to mechanical issues with the reader (e.g. the feed spool sticking).  Again, so far this hasn't resulted in any apparent errors in the decoded data.

5. A slight non-uniformity in hole spacing as they appear in the video image.  This may be due to an optical distortion effect in the video recording device, or slight inclination of the recording device relative to the tape.  I have given  some thought to enhancing the tape-tracking logic to use residual errors to estimate a correction for this, but so far this hasn't proven to be necessary.

Most of these errors may be fixed by further tuning of analysis parameters, though there may be other errors which haven't been picked up by internal consistency checks.

## Media player software

In fine tuning the video analysis process, I have found that examination of the synthesized visualization of the data analysis has been a very important tool.  A challenge has been that many commonly-available media players do not provide for backward single-frame stepping of the video.  Because the data analysis pipeline lags the actual video data, it is important to be able to step backwards from the point that a pipeline error is apparent to examine the corresponding video frames.  (I'm using a MacBook with an M1 processor for running the analysis, though the code itself should be portable to other systems.)

Researching this issue, I found a free media player [SMPlayer](https://en.wikipedia.org/wiki/SMPlayer) that does support backwards frame-stepping, which is what I routinely use when viewing the generated videos.

Another media player issue is that the code generates an AVI video file, which does not play reliably in Apple's Quicktime player (though SMPlayer is fine with it.  This file is also very large (I've been seeing about 7Gb for a 12 minute video); I think this is mainly because my software doesn't generate keyframes, hence the resulting video is relatively uncompressed.  In order to create a smaller file (about 1Gb) that works with Quicktime, I use Apple's Final Cut Pro to convert the video from AVI format to MP4 (`.m4v`), which I use for publishing the videos.

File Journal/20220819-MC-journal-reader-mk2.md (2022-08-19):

<!-- 20220819-MC-journal-reader-mk2.md -->

It's been a slow time since the last journal entry, during which we've:

1. prepared and presented a poster about our work to date at the Oxford Digital Humanities Summer School, and 

2. worked on a revised design for the tape reader, attempting to overcome some problems with the previous design.

The poster can be seen at [20220516-DHOxSS-Monotype-Reader-poster.pdf](../Notes/DHOxSS-poster/20220516-DHOxSS-Monotype-Reader-poster.pdf), and describes in very broad terms the work to date to extract data from the Monotytpe tape. 

## Monotype reader Mk2

A number of problems were noted with the original Monotype tape reader design:

1. Tape movement would become stiffer as take-up spool filled up and caused the tape to become more difficult to draw smoothly over the read head.  This in turn meant that video quality towards the end of the tape became poorer, and data could not be decoded effectively.  (When the tape moves more quickly over the read head, fewer video frames mean that holes in successive tape rows can be missed out or merged, resulting in loss of data when the video is analyzed).

2. The phone camera support was rather flexible, which resulted in undue camera movement and reduced video quality, particularly as the take-up spool became fuller (see above).

3. Tape skew as it passed between the spools meant that it would be forced against the guide rim of the read head or take-up spool, potentially causing damage to the tape.

Changes were made to the tape reader design to reduce these problems:

- The baseplate was extended in an attempt to reduce tape skew and hopefully reduce pressure from the guide rims on the paper tape.

- Additional bracing structures have been designed into the base plate to make the camera mount stiffer.

- The take-up spool core diameter has been increased to reduce the proportional variation in diameter as tape is wound onto the spool.

- A speed reduction between the winder crank and the take-up spool has been implemented by way of a pulley drive from the crank to the spool, to compensate for the larger spool core, slowing down the speed at which tape is drawn over the read head for a given rate of turning the crank.

These changes were only partially successful:

While the tape skew may have been reduced, this did not help the problem of tape being forced against the guide rim of the take-up spool; if anything, the resulting design is more prone than the original to damage the tape, and the problem of guiding the tape needs to be re-thought.  A factor here appears to be drag in the tape path resulting in the tape being under some tension as it is drawn over the read head.  

The extended baseplate has also meant that the available length of leader tape is not enough to reliably attach under the clips used to hold them on the winder spool cores -- until there is enough tape wound around the core, the core just slips and the tape is not drawn across the reader head.

The stiffened camera mount seems to be working OK, particularly when the baseplate is clamped to a stable service when operating the reader.  I've yet to test this in a recording of the full length of the test tape.

It's too soon to tell for sure, but the winder crank speed reduction seems to be working OK.  Originally I tried using rubber bands for the reduction-drive belt, but these proved too stretchy and it was difficult to maintain a steady tape speed over the read head.  So I changed to using a PU (polyurethane?) belt material which can be "welded" to a desired length, which seems to be working reasonably well.  (I have been trying to ensure that the drive belt will slip if there is undue force needed to turn the take-up spool, in an attempt to reduce the likelihood of tape damage if something should jam.)

If it turns out that the hand-winding is still a problem for maintaining a steady tape speed, I'm ready to start thinking about using a stepper motor to draw the tape.  This would incur considerable additional effort to include electronics and/or software to drive the motor, but should make it much easier to maintain a steady speed.  One of my original concerns with using a motor drive was that the force applied to the tape might be higher than desirable, but this would be less of a concern if using a pulley-and-belt drive system.  This change, if implemented, will be for a subsequent version of the tape reader.

## Monotype reader Mk3

This leads me to consider a number of changes to be made for a 3rd version of the tape reader.

1. The main change will be to re-think the tape-path guides.  So far, I have attempted to use static rims that guide the edge of the tape.  But when the tape is being drawn under some tension, it can be forced against the rims causing the edge of the tape to be scuffed and potentially damaged.  My next thought is to use idler sprockets to guide the tape by its sprocket holes, eliminating sliding contact with the edges of the tape.  These guide sprockets will replace the bars that currently guide the tape over the read head, and should also reduce drag in the tape path, thereby reducing the force needed to draw the tape.

2. The tape spools can be made longer (wider than the tape) so that the rims serve primarily to protect the tape, not to guide it.  Ideally, the edges of the tape will never touch the spool rims as the tape is drawn through the reader:  I'm hoping the guide sprockets will ensure this is the case.  At the same time, make the baseplate wider, allowing more end-float for the winder spools.

3. Use a 3-spoked design for the tape spools to reduce the amount of plastic used in their manufacture, and also to make them lighter.

4. Include a small raised inner hub on the support brackets for the tape spools, to avoid the spool rims rubbing against the brackets and causing additional drag.

5. Shorten the tape path.  The original baseplate design could be 3D-printed as a single piece on the Prusa printer.  The Mk2 design has to be printed as two separate pieces that are held in position by the support brackets for the read head.

6. Redesign the tape clips to slip on and off the winder spools, and revise the design (maybe with a mating bump and recess?) so that they do not slip around the spool cores.

The immediate next step will be concentrate on redesigning the tape-path guides (item 1).  If successful, I judge that this alone should make a big difference to the usability of the tape reader.

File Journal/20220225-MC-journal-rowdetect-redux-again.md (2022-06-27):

<!-- 20220225-MC-journal-rowdetect-redux-again.md -->

## 20220225: Row detection revisited again

Just as I was preparing to move ahead to extracting data from detected rows in the Monotype tape video, I noticed that the row detector I'd built wasn't performing very well over the length of the tape.  There were two apparent reasons for this (probably mentioned previously): (a) variations in the speed of the tape, in particular, when the tape was moving in a jerky fashion such that some holes were visible for just one or two frames, and (b) the tape being skewed as it passed over the read head, so that not all holes in a row were exposed at the same time.

A simple engineering solution to this problem would be to just make a better quality video.  But I have been finding value in at least trying to work with the messy data I have, generating insights and motivations for visualizing the data that may or may not be useful in the longer run.  So I've revisited the row detection logic again.

I had already been thinking about using a variation of the RANSAC algorithm [1] to match tape holes to Monotype matrix coordinate data.  Now I decided that I needed to employ something similar for row detection.  Previously, I had been assuming that all holes in a row would be jointly visible at some instant.  The tape skew problem mentioned above meant that this isn't always true.

[1] https://en.wikipedia.org/wiki/Random_sample_consensus

I've decided that I need to look for groups of traces (corresponding to holes in the tape) that lie very close to a line.  This will involve finding a seed set and, if they sufficiently satisfy the straight-line criterion, look for additional traces (holes) that can be added to that set while closely maintaining that criterion.

The original algorithm would look for holes that are visible together and assume that they correspond to a row  of tape data.  Much of the time, this criterion works well, and (based on empirical observation of the data) it is very rare that at least some holes in a row fail to be visible together.   So, rather than using random samples to create seed sets, which is what RANSAC does, I am choosing to look for seed sets of holes that are visible together.

To assess how well a set satisfies the straight-line criterion, I perform a simple linear regression fit [1] of a straight line through the values of the set, then calculate the mean of squared deviations of the values from the line.  The resulting value, called the _residual_, or _residual error_, is a measure of how closely the points meet the straight-line criterion.  

[2] https://en.wikipedia.org/wiki/Simple_linear_regression

Some empirical experimentation has been performed to determine an appropriate maximum value for the residual (error), and also to tweak the exact formula by which the residual is calculated.

Some further complications arise because there are multiple rows in the data, and it is sometimes possible that a particular hole might be matched with more than one row, while each hole in the tape must belong to exactly one row of data.  For example, _any_ pair of holes can be perfectly fitted to a straight line (i.e. with zero residual).  So some additional logic is used to allow several candidate rows to be considered, from which the "best" one is chosen.

Some additional work has been performed on the data visualization to help identify misallocation of traces holes) to rows while evaluating the evolving row-detection algorithm.  E.g., using different colours for unallocated traces and those assigned to alternating rows.

I also spent a few weeks exploring a computer algebra system [4,5] in search of a more direct way of assessing how closely a set of values matched the straight-line criterion.  Thus far, I have been unsuccessful and have resorted to a "brute force" approach to evaluating the residual, but it was an interesting diversion, and might prove a useful tool for working with, for example, some aspects of complex 3D designs.

[4] https://maxima.sourceforge.io/
[5] https://wxmaxima-developers.github.io/wxmaxima/

## Thinking about art and research

(This commentary motivated in part by my decision to "waste" several weeks exploring parameter estimation ideas and computer algebra systems as part of the activity described above.  Was it truly wasted?  I can't say at this time, but I feel I have some further process insights that might just prove useful later.)

It has struck me that there is some similarity between the process of creating an artwork and performing academic research.  Both are striving for some element of novelty, or uniqueness, in the result they produce.  This in turn requires some awareness of other related work - this is a given for academic research, and I have often noticed other artists asking "Have you seen the work by X?" when I offer a suggestion for how an idea might be developed and presented.  Yet the goals are different:  research (in science and engineering) generally aims to create new knowledge, where I would suggest that art is more aiming to create new forms of expression that connect people with ideas or concepts.  Research in humanities, as I perceive it, does a little of both.  Yet it seems to me that the process of exploring a space of ideas, doing experiments and seeing what they reveal, is similar in both (see also "Plans and performances: Parallels in the production of science and music" [3]).

[3] https://ora.ox.ac.uk/objects/uuid:8507e218-aa8f-4242-9fe8-9ef29ed69bf5

Compared with straight engineering, both art and research (as an ideal, if not always in the academy) seem to value the process of exploration and discovery as much as the eventual published or exhibited result.  This in turn seems to affect the way that work is conducted, with greater interest in exploring backwaters (and rabbit holes) along the way to some desired end goal.  (At least, when not overly bound by resourcing constraints?)

@@TODO Implications:

- process?
- funding?
- dissemination?
- critical acceptance?
- public acceptance?
- sharing (open vs not)?

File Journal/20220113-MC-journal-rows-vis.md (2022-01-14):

<!-- 20220113-MC-journal-rows-vis.md -->

## 2022-01-13: Row detection and visualization redux

I've had a bit of a hiatus from the project over Christmas, and it's also taken me a while to get my head around the processing needed to group traces (see [2021-11-26 journal entry](./20211126-MC-journal-rethink.md)) into rows corresponding to codes punched in the Monotype tape.

If the data were perfectly clean and regular, it would be relatively easy, but several factors, including tape skew, small camera movements and most of all wide variations in the speed that the tape moves over the reader bar, mean that a simplistic analysis is likely to be fooled by unexpected variations.  Ultimately, any analysis can be thrown if the source data is sufficiently distorted from what is expected;  as they say "Garbage In, Garbage Out".   But as long as there is enough data (which in this context means sufficient video frames for each row of holes passing over the reader bar), I'm hoping to design processing algorithms to do a decent job of extracting data from the tape.  The extra design and programming effort this entails is part of the original trade-off made when choosing a design strategy for reading the tape:  simpler hardware compensated for by "smarter" software.  (The original Monotype System didn't have this choice, and the mechanics of that system are a wonder to behold!  But thgey are way beyond my capabilities to replicate for this project.)

Without going into details, I believe I have now devised a reasonably robust process for detecting rows in the Monotype tape video.  The code will eventually be public in GitHub project [opencv-video-data-extraction
](https://github.com/gklyne/opencv-video-data-extraction/blob/main/video-06-row-detect.py).  Look for function `trace_row_detect` and class `region_trace_set` for the central logic used for row detection.  I fully expect the details to be revised as the project progresses, so this link will not necessarily reflect the latest version.

### Video data processing

My various experiments with video data processing are leading me to think more broadly about the nature of computer vision.  As [noted previously](./20211101-MC-journal-temporal.md), I might have used machine learning to figure out how to extract data from the video, but that would have required access to a significant body of labelled video data, something that I don't have.  So it comes down to me to figure out how to process the video data.

It became evident early on that the processing would take the form of a pipeline, with each step in the pipeline reducing the data and passing results to the next step.  Early pipeline steps dealing with pixel-level data would need to be optimized for speed because of the sheer number of pixels present in a video.  So, as far as possible, the early processing stages use optimized functions in the [OpenCV](https://opencv.org/about/) library.  Later pipeline steps working with higher level concepts are implemented in code that I am writing in the [Python language](https://www.python.org/).

So far, the processing pipeline looks something like this:

1.  Read video.

    The result is frame-by-frame pixel data, where each pixel is an RGB colour value.

2.  Detect highlight regions (mostly consisting of holes in the tape passing over the reader bar, but also some extraneous regions).

    The result is frame-by-frame pixel data, where each pixel is a binary (on/off) value

3.  Highlight region detection, where adjacent pixels are merged into regions.

    The result is frame-by-frame region descriptions, where each region has calculated centroid coordinates derived from the constituent pixel coordinates.

4.  Filter obviously spurious regions, to speed up subsequent processing

    The result is still frame-by-frame region descriptions.

5.  Trace detection, where a "trace" represents a nominally stationary region through multiple frames.  The intent is that each trace corresponds to a hole in the tape being drawn over the reader bar.

    The result is a list of trace descriptions, approximately ordered by their appearance in the video (specifically, ordered by the video frame in which the trace ends).  Each trace description records its starting and ending frames, and its spatial location within those frames.

6.  Row detection, where each row consists of traces grouped into sets that overlap temporally.  The intent is that each row represents a row of holes being drawn over the reader bar, and while there may be some variation in the timing of their detection, it is assumed that there will be at least one video frame in which all holes in a row are detected together.  Detection is complicated by the fact that rows may overlap, and in such cases the software needs to decide the row to which each particular trace should be assigned.  Also, there will be some spurious traces that could not be reliably eliminated in step 4.

    The result is a list of row descriptions, where each row consists of a set of traces, approximately ordered by their appearance in the video.

7.  The next step, which has not yet been implemented, will be to analyze the traces in each row, and decide which of the possible holes in the Monotype tape they correspond to; i.e. to extract a punched tape code for each row.  This will need to take account of the fact that there may still be spurious traces in some rows, and some holes (particularly sprocket holes) sometimes fail to be detected in earlier processing steps.

This notional processing pipeline is itself the result of some trial and error from working with the data.  It has occurred to me that choosing appropriate intermediate processing steps is a substantial part of designing the overall video analysis process.  It has further occurred to me that choosing useful intermediate representations is a big part of what deep neural network learning is able to automatically achieve from its input data.  The adjective "deep" here refers to multiple intermediate layers of representation that are inferred from processing the raw input data.   So in some ways, this process of experimentation with data and pipeline alternatives might be regarded as analogous to how deep learning operates.

### Visualization

For me, an interesting aspect of this work has been thinking about how to visualize data that is being extracted from the video.

Unlike a deep learning network where intermediate representations are hidden and largely not amenable to human interpretation, my approach requires gaining knowledge of the characteristics of each of the intermediate representations, so that I can judge what processes might be effective in moving towards the end goal of decoding data from the type.  When dealing with large amounts of data, visualizations are very helpful towards this end.

A notable feature of the processing pipeline is that processing moves from being primarily spatial (describing features in terms of their positions of within a video frame) to temporal (describing features in terms of when they appear in the video).  Ultimately, what we need to describe is neither temporal, or spatial, but a sequence of yes/no values corresponding to each hole position across the Monotype tape.

I have been devising visualizations with the primary aim of showing me how the algorithms are handling the video data presented, showing results from steps 1, 2, 3, 5 and 6 of the processing pipeline (see above):

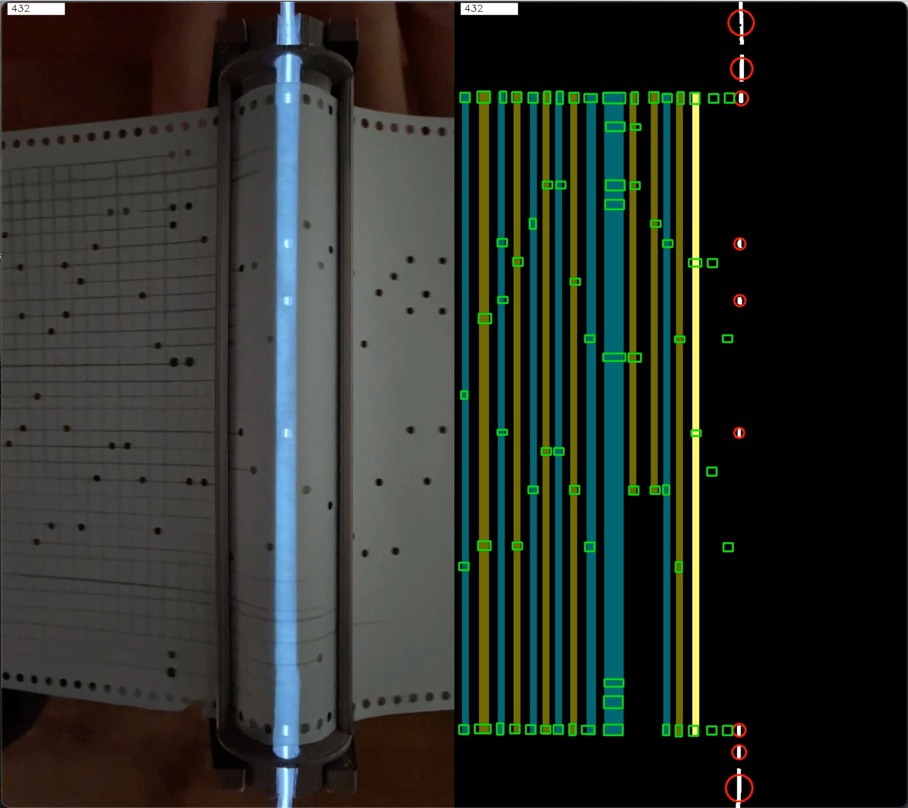
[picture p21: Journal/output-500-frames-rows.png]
Screenshot of video processing visualization


The screenshot of a single frame of the visualization video shows the original video side-by-side with results from the processing pipeline:

- The original video (step 1) is shown in the left half of the display.  The video frame number is shown at the top.

- the highlighted areas (step 2) are shown as white areas in the right half of the display.

- merged highlight regions (step 3) are shown as red circles, centred on the region centroid and with area proportional to the actual area of the region.

- traces (step 4) are shown as green rectangles.  The position is based on the region centroid, but with the horizontal position offset so that older traces move away to the left. The width of the rectangle is based on the duration of the trace (in video frames), and the height is adjusted so that the area of the rectangle matches the area of the region summed over all of the frames in which it appears.  The effect of this is that traces that appear for longer in the video (e.g., when the tape is moving more slowly) are wider in the visualization.  This is the first step in which the visualization moves from being entirely position-based to becoming both position- and time- based.

    (This visualization could be made to look more like the original video by offsetting the vertical position using a function of the frame number so that the trail of traces appears to recede into the background.  Reducing the brightness of the trace outline might also add to the receding effect.  There are many ideas that could be tried here.)

- detected rows (step 6) are shown as vertical bars that overlap the traces that have been grouped into rows.  The vertical position and height of the bars is calculated to cover all of the traces.  The width of the bar is calculated to cover the duration for which all of the traces are present in the video (so a very narrow bar might indicate one or more of the traces being present for a very short period, or some of the traces starting and stopping sooner or later than the others).

    The alternative colours of the row bars are mainly to make it easier to distinguish successive rows, but also highlight when the row detection order occurs out of sequence with their position on the tape.  So, for example, the screenshot shows two blue-ish bars adjacent on the display.  One of these bars is noticeably wider than the other.  This is due to the way that row detection works:  when the traces in a row have longer duration (here due to a brief pause in the speed of the tape), the algorithm waits longer (i.e., looks further ahead in the data) to ensure that no subsequent traces will be added to this row.

These explanations are intended to show how the visualizations presented are not entirely arbitrary (even if they contain some arbitrary choices), and their creation owes little to aesthetics.  Yet feedback from others involved with the project suggests that they are visually interesting in their own right, which maybe hints at the possibility of a previously unplanned "Monotype Composition" arising from Clarice's diary?

This visual interest suggests a further question:  is this visual interest somehow related to capturing significant features of the underlying data and the processes?  Are our human perceptual capabilities somehow catching these underlying processes and drawing our attention to them, even if we are not formally aware or able to articulate what is being presented?  And, if so, can  we exploit this effect to create more artifacts that reflect other underlying information patterns in artistically compelling ways?  In a sense, I think, such explorations lie at the heart of the Monotype Compositions project.

### Glossary

In writing these journals, I'm realizing that I need to use some words with quite particular meanings within this project:

- **Monotype tape**: a paper tape produced by the Monotype system Keyboard.  The tape is about 110mm wide, and has 31 hole positions across its width, as well as sprocket holes on each side.  The sprocket holes are present in every row; other holes are present or not present according to the character or end-of-line control being encoded.

- **Tape reader**: is a physical device designed and constructed to record a video of a _Monotype tape_ being drawn over a _reader bar_.  Data encoded as holes in the tape is extracted by software that analyzes the recorded video.

- **Reader bar** or **reader bridge**: a part of the _tape reader_ that illuminates successive rows of holes in a Monotype tape.  The tape holes passing over the reader bar appear in the recorded video as bright regions, the position and timing of which is analyzed to extract the tape-encoded data.

- **Highlight region** - or **marker**: a bright region in the recorded video that is seen when holes in a Monotype tape pass over the reader bar.  There may be other spurious highlights that show up in the video - part of the task opf the analysis software to to distinguish these from actual hole data, and discard them.

- **Centroid**: the computed centre of a region in a single frame of video.  This is a kind of average position over all of the pixels that make up the region, and is used as an estimate of the position of the centre of a hole pouched in the tape.

- **Trace**: the appearance of a single _highlight region_ in several successive frames of a video.  Each hole passing over the reader bar is expected to be visible for several frames, and thus represented as a trace.

- **Row**: a set of _traces_, each corresponding to a single hole in a Monotype tape, that correspond to a single character or control code encoded in the tape.

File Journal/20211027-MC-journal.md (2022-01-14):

<!-- 20211027-MC-journal.md -->

## 2021-09-06: Building the tape reader

In the early days of discussing the Monotype Compositions project, I envisaged a workflow that would involve digitizing the Monotype Ribbon tape, and  using the resulting data to generate MIDI data as a way of experimenting with different ways of sonifying the data -- there are so many ways that sound could be generated, and I wanted to be able to experiment before committing to a physical mechanism for "playing" the tape.

This led me to thinking about what might be the easiest way overall for reading data from the tape.  A purely mechanical reading method was likely to require lot of mechanical design experimentation, something that could be time-consuming, and that I don't feel well equipped to undertake.  Similar considerations apply to an electro-mechanical reading approach (e.g. passing the tape over light sensors connected to a data-logging computer such as a Raspberry Pi).  As a software engineer, I sought to simplify the mechanical aspect as much as possible, and to do the difficult parts in software, on my "home ground" so to speak.

The approach I've adopted (at least initially) is to use a simple mechanical device to draw the tape over a slit light source, and video the result using a mobile phone.  Then I would transfer the video to a computer and use software to detect the paper tape holes as they pass over the light source, and write software using existing video processing libraries to extract the Monotype typesetting data represented by the tape.  This would still require some mechanical device to pass the tape over the light source, but the need any mechanical or electromechanical reader components would be avoided.  An initial design sketch was created quite quickly using OpenSCAD, a CAD tool that can be used to create shape descriptions for 3D printing.  Further progress would require a 3D printer to realize the designs.

Some time passed before I had access to a [Prusa 3D printer](https://www.prusa3d.com/product/original-prusa-i3-mk3s-3d-printer-3/).  After some initial experiments to familiarize myself with the printer and its associated software (which I found were a joy to use compared with the RepRap Mendel printer I had assembled over 10 years previously), I started to explore how to realize my outline designs.  Not being a skilled mechanical designer, It turned out that I needed several iterations to create a design that would work - many parts were tried in 4 or more design variations before settling on a construction that appeared to be usable.

The device itself is about as simple as I could imagine: a hand-cranked spool that would draw the Monotype Ribbon tape over a reader bridge with an embedded electroluminescent (EL) wire to provide illumination.  And a support arrangement to hold a mobile phone in the right place to record a video of the tape being drawn over the illumination.  Even designing such a simple device proved to be most useful as a way to refresh and improve my 3D object design skills (which yet remain quite rudimentary).

The design software I use, OpenSCAD, uses a textual representation of the designed parts that is rather like a programming language that described how to create the designed shape from a combination of simpler shapes.  It's a technique known as Constructive Solid Geometry, or CSG.  Because the shape definition is textual and has a well-defined structure, it would be easy to create these descriptions in software.  This led me to start thinking about possibilities for using the Monotype Ribbon data to control the creation of physical artifacts that might be played by some device, and the possibility of deepening public engagement through accepting offerings of data that can be used to create alternative objects that could be played by the "music box".  This could then use Claris Spratling's diary as a springboard to a much wider landscape of sonified text and other data.  These are just some vague ideas, and will need much more thought if they are to be pursued as the project evolves.

## 2021-10-11: Recording the video

At this point, I have a basic device that I can use to create a video recording of the Monotype Ribbon tape data.  The design always intended tom use software to compensate for any speed variations, but this would depend on having enough data recorded to be able to reliably detect each row of data.  

Making the recording turned out to be trickier than I expected.  To begin with, it was easy enough to turn the handle at a steady rate that would draw the tape slowly over the reader bar, with several video frames for each row of data.  But as the tape built on on the winder spool, it became harder to maintain a steady rate.  Also, the tape would start to wander from side to side, and snag on the winder spool rims and reader bridge guides, with attendant risk of damaging the tape.  Towards the end, I found myself drawing the tape over the bridge directly, expecting software to ignore the resulting pauses as I moved my hand to grasp the next length of tape.  But it was difficult to do this at a sufficiently slow speed, and some of the rows of data had very little data for reliable row detection.  

As I write this, I still don't know if I'll be able to fully analyze this early recording, but it provides a useful set of test data for testing analysis techniques.  I have since redesigned the winder spools and reader bridge to provide better control of the tape, and it does appear to be possible to wind the tape through from end to end.  I have yet to test this with a new recording.

A concern here is that the paper tape is not very strong, and might easily be damaged if it is not treated gently during the recording process.  It also leads me to think that a device to play the tape directly will need a much-improved mechanical design to avoid undue wear of the tape (of which we have just one copy of those used to print Clarice's diary).  This is one reason that I've been keen to use hand power to draw the tape, as a human operator can quickly detect any snagging of the tape and release the winding force before the tape is damaged.  The other reason is simplicity.  But it might be easier to achieve a slow, steady rate of tape advance using some form of powered drive.  

Considering a powered tape winding mechanism, my initial thought would be to use a stepper motor, but that would require a special controller and some software to provide the control signals.  I expect this would not be hard to achieve using a Raspberry Pi and off-the-shelf accessory hardware, but that would be an additional layer of complexity, and I'm keen to see if I can successfully extract data without taking this step.

## 2021-10-27: Processing the MT video

I've been using computer vision software libraries to extract data from a video recording of a Monotype Tape Ribbon being passed over an illuminated light source.  The idea is that by detecting the bright areas in the video as the tape is being drawn over the light, I will be able to detect and extract the Monotype Caster typesetting data.

Something that has been surprising to me is that the videos themselves have been seen by John as potential exhibits in their own right, where I have been seeing them primarily as a means to end.

In developing software to decode data from the video, I have also been generating some part-synthetic video that represents data from the decoding process:  the software is generating a "split-screen" video with the original video on the left hand side, and a synthesized video, representing data from the video processing pipeline, on the right hand side.  The initial purpose of this video is as a software debugging and monitoring tool, to help me see how well the software is doing at extracting information from the video.

Feedback from both John and Dawn has pointed out that the data patterns highlighted in patterns of the synthesized video have an aesthetic quality of their own, which, for example, is suggestive of rhythms that might be used when subsequently sonifying the typesetting data.

These comments have piqued my imagination about possibilities for presenting the video as an exhibit.  I have this idea of generating a display a little like The Matrix screen of "dripping" characters:  the detected highlights from the video might be moved along to match movement of the tape, yet changing in intensity and/or colour, becoming an alternative rendering that might, for example, be used as a "video backing display" for the sonified data.

Eventually the tools that I'm developing for debugging the video decoder might be repurposed as part of a final exhibition, maybe generating video as well as sound from a 3D printed rendering of the Monotype typesetting data.

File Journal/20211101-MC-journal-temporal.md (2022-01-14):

<!-- 20211101-MC-journal.md -->

## 2021-11-01: Temporal video processing: row detection

Previously, I have achieved some success detecting the video highlight regions that correspond to holes in the tape passing over the electroluminescent (EL) wire in the Monotype Tape read head.

I have also applied processing to merge adjacent and near-adjacent pixels into regions, with a coordinate location for each region.  This is an important step of data reduction, as each region corresponds to up to 150 individual video pixels, and for the most part I'm seeing that these detected regions do indeed correspond to holes in the paper tape.  There are also some additional regions detected where the EL wire is never obscured by the tape, but I'm happy to keep these in the data as they will help me later to confirm that the typesetting data decoding process embodies a degree of robustness (i.e. can still generate good output data in the face of some spurious input data).

All this has, so far, been based on processing each frame of video data independently, with no consideration of what comes before or after.  Since then, I've been spending some time thinking about how to incorporate temporal information from the video.  The challenge I have set myself is to detect and merge data from each row of holes as it passes over the read head.  Each such row will eventually correspond to a single "frame" of typesetting data that can be used for subsequent sonification experiments (like the rows of pins on a musical box drum, maybe).

Because the tape is being drawn over the read head by hand, its speed will vary, so I cannot rely on timing information to distinguish the rows.  Instead, I will look for multiple regions that appear and disappear together, corresponding to rows of holes passing over the read head.  Between these rows there should be periods when there are no regions present in the absence of spurious data.  I am partly relying on the fact that the sprocket holes in the tape will help to provide a regular heartbeat, even when there is no data on the tape.

That, at least is the theory, but the practice is not quite so simple, because:

- the tape may be skewed relative to the read head, and the holes in a row don't necessarily all appear and disappear at the same time,
- there is spurious data that means that regions appear in the data even when there are no regions corresponding to tape holes,
- the speed at which the tape passes over the read head means that a region may sometimes appear as two separate regions, or be missed entirely in some frames,
- the camera shakes, and the tape wanders a little while being drawn over the read head, so the position of a hole may vary slightly from frame to frame.

All these factors are things that I've noticed by devising processes for decoding the data, and then watching the decoder in operation, comparing the detected row data with the original video and highlight regions.  This exposes a key difference between the video decoding process I am trying to understand, and more conventional scientific and engineering code I have worked on previously.  The nature of the input data means that it is very hard (for me: not possible) to devise an algorithm for the processing based on prior knowledge of the data.  Rather, this is a process of exploration of the data, and experimentation with different approaches to processing it [1].  Much of the code I am trying out is aimed at displaying the data in ways that expose how the decoding processes are working.

<footnote>
[1] It might be suggested that an appropriate way to processing such data would be through machine learning (ML).  As it happens, I have been reading Marcus du Sautoy's "The Creativity Code" (which explores the use of ML for creativity) during the period that I have been exploring the video decoding problem, and have thought a little about this: am I using an altogether wrong approach in my trial-and-error approach to the video decoding?  To date, I have formed a view that I cannot use ML without a large amount of labelled data, which I don't have.  I believe the effort required to create sufficient such data would exceed that my current approach of experimentation with decoding algorithms.  It might be said that I am following the same process as a machine learning algorithm, but with the advantage of some human insight and contextual awareness when making adjustments to the algorithm.  And, unlike most machine learning, I have reasons for the choices I make that can be articulated, and in the process may gain greater personal knowledge of the nature of the data.  Maybe there's a topic here for interesting philosophical debate about the types of evaluation and learning needed in creative activity?
</footnote>

I am reminded of a discussion I once had with a digital humanist about differing approaches to dealing with humanities data vs scientific/engineering data.  They mentioned to me that it was sometimes important for a humanist to immerse themselves in their raw data, to consider what it might (and might not) be conveying, before deciding how to process it.  I feel there's a similar dynamic at work with the video data: I need to spend time with it, getting a feel for what constitutes meaningful patterns, before I can finally decide how to process it.

My process of video data exploration is highly dependent on computer processing.  While a human would easily enough look at some specific video and say what data it represents, that would take too long given the amount of video to be processed, so I am looking here for a pattern that can be systematized and automated.  There are just too many pixels in a single video frame for a human brain to fully discern a general pattern in how they correspond desired output data.  Instead, the data needs to be processed, reduced, presented and visualized in ways that one can discern possible ways to decode the data.  This is the nature of the experiments I am undertaking, and along the way maybe producing renditions that are of themselves worthy of exhibiting as artworks - maybe because of the ways that they help to provoke human perceptions of what is hiding in the data?

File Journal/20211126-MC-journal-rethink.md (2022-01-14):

<!-- 20211126-MC-journal.md -->

## 2021-11-26: Temporal video processing: row detection rethink

Previously, I discussed the importance of becoming familiar with the data I'm trying to process.  What I have been trying to do is systematize a way of detecting when each row of holes passes over the reader head, given the various complications noted previously.  And over the past couple of weeks, I've hit something of a block.

The other morning I had an insight - one which, as a software engineer, I should have seen much sooner.  I have been trying to do too much all at once.  I had assumed that I could detect rows of tape holes by looking at just frame-by-frame data.  But sometimes, the rows are not separated neatly along frame boundaries:  for any given frame, one column may be seeing data for one row of tape holes, while another column has data that is part of a preceding or following row.  This may occur, for example, when the tape is skewed passing over the reader bridge, or the camera angle is slightly perturbed from its ideal orientation in which each row is exactly aligned with one of the image axes.

So, if I can't apply row detection on a (video) frame-by-frame basis, what else can I do?  I could go back and redesign the reader device to give cleaner data (something I fully expect to do at some stage), but I still want to make the data decoding as robust as I can make it, so I'll push ahead with the imperfect video that I have.  

So, I need to devise a form of row detection that work across multiple frames.  My new insight is that I can apply a further step of data reduction before attempting row detection.  Instead of working with frame-by-frame feature centroids (where the "feature" here is a bright part of the image where a tape hole is passing over the illuminated slit), I have decided to combine these into "traces" that extend over multiple frames.  Then, my thinking goes, I can look for multiple traces that all have a start and an end, and substantially overlap in the frames where they appear.

I have implemented a "trace detection" algorithm, and a new visualization that shows recent traces edging there way across the image.  (The visualization looks a bit like the moving tape holes, but the movement shown is based on the passage of time, not the movement of the tape.  The width of a displayed feature is dependent on how long it remains visible.  Thus, if the tape moves more slowly, the displayed features are wider.)

As far as the reader hardware is concerned, there are some changes I want to make:

1. Make the camera mount more rigid, so it doesn't sway about as much when the tape is being drawn over the reader bar.
2. Increase the core diameter of the winder spools so there is less change in the overall diameter as tape accumulates on the take-up spool.
3. Implement some kind of winder gearing to make it easier to draw the tape at a steady slow speed.
4. Move the winder spools further from the reader bridge, so there is less opportunity for the tape to be skewed over the reader bridge.
5. I have contemplated trying to implement some kind of sprocket feed to more accurately guide the tape over the reader bar.

It may be worth emphasizing that all these changes have been prompted by working closely with the data, and building insights into its imperfections.

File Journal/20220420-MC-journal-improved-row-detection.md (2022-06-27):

# 20220420-MC-journal-improved-row-detection

## Improved row detection

After some time exploring the mathematics of direct calculation of a row-fitting residual (a statistical measure of how well a chosen set of markers correspond to a row), I gave up and went for a brute force approach; _viz_ to calculate the equation of the fit, then calculate the residuals.  This involves making two passes over the data, but in the event is not unreasonably expensive.

Moving on, the next step was to use this residual evaluation function in the identification and separation of data from different rows of the tape.  A variation of the RANSAC algorithm is used, in which multiple combinations of markers are selected and evaluated, and only those that meet minimum levels of conformance are considered as possible rows.  From these possibilities, the best matches are chosen.

A problem I encountered is that sometimes there are what appear to be "better" fits (in terms of the calculated residual) that actually cross over multiple rows of tape holes.  Statistically, given enough data, such anomalies are bound to occur from time to time, but they were happening more frequently than I considered acceptable for the task of decoding the tape data.  Yet, using the visualizations described previously, a human observer would immediately spot these errors.

Reflecting on this perception vs algorithm discrepancy, I came to a view that the human observer would also take note and avoid interpretations that allowed rows to cross over, or left potential matches unused.  That is, it would consider more than a single row in isolation.  A revision of the basic algorithm selects pairs of candidate rows and chooses based on the combined residuals.  This is a pretty crude way of extending the evaluation to consider multiple rows, but in practice did pretty well at eliminating many of the errors that were obvious to human observation:  at the time of writing, this is how the row detection is implemented.

This whole development has served to illuminate differences between human vision and object recognition, which operates in parallel and easily recognizes patterns in a larger context, and algorithmic recognition, which operates sequentially and is more easily conceptualized (by a programmer) as a series of sequential steps that reduce context and hence options from which matching patterns are selected.  

Visualization has continued to be a powerful tool for identifying and isolating cases where the row detection algorithm gets it wrong, yet largely avoiding the need for closer analysis in the majority of cases where the algorithm performs as desired.  This is an example of a technique combining computational speed and easy repeatability with the power of human perception.

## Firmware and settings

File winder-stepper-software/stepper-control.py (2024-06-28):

# stepper-control.py

# To set up environment:
#
# SSH to RPi:
#  ssh graham@192.168.1.23  (p:a...?)
# or:
#  ssh graham@mcreader.local
#

# venv notes (NOT NEEDED)
#
#  $(which python3) -m venv venv
#  . venv/bin/activate
#  pip install --upgrade pip
#  pip install wheel
#  pip install RPi.GPIO
#

import sys
import tty, termios
import time
import select
import RPi.GPIO as GPIO

def get_stdin_char():
    # See: 
    # 	https://stackoverflow.com/questions/37726138/disable-buffering-of-sys-stdin-in-python-3
    # 	https://docs.python.org/3/library/tty.html#module-tty
    #
    buf   = ""
    stdin = sys.stdin.fileno()
    tattr = termios.tcgetattr(stdin)
    try:
        tty.setcbreak(stdin, termios.TCSANOW)
        # Is stdin ready to read?
        si, _, _ = select.select([sys.stdin], [], [], 0)
        if si:
            buf += sys.stdin.read(1)
    finally:
        termios.tcsetattr(stdin, termios.TCSANOW, tattr)
    return buf if len(buf) > 0 else None

def next_step(stepseqnum, stepdir):
    stepseq     = [ [1,0,0,1],
                    [1,0,0,0],
                    [1,1,0,0],
                    [0,1,0,0],
                    [0,1,1,0],
                    [0,0,1,0],
                    [0,0,1,1],
                    [0,0,0,1] ]
    steplen     = len(stepseq)

    stepseqnum += stepdir
    if stepseqnum >= steplen:
        stepseqnum = 0
    if stepseqnum < 0:
        stepseqnum = steplen+stepdir
    return (stepseqnum, stepseq[stepseqnum])

def stepper_pins(motornum):
    #
    # motornum is stepper motor number 0-3 (assumes pistep2 interface)
    # See: https://thepihut.com/products/pistep2-quad-stepper-motor-controller-for-raspberry-pi
    #
    # Physical pins 11, 12, 13, 15 for Motor A (GPIO 17, 18, 27, 22)
    # Physical pins 7, 22, 18. 16 for Motor B (GPIO 4, 25, 24, 23)
    # Physical pins 33, 32, 31, 29 for Motor C (GPIO 13,12,6,5)
    # Physical Pins 38, 37, 36, 35 for Motor D (GPIO 20,26,16,19)
    #
    motorpins = [ [17, 18, 27, 22],
                  [ 4, 25, 24, 23],
                  [13, 12,  6,  5],
                  [20, 26, 16, 19],
                ]
    steppins  = motorpins[motornum]
    return steppins

def stepper_init(motornum):
    # Use BCM GPIO references instead of physical pin numbers
    GPIO.setmode(GPIO.BCM)
    steppins  = stepper_pins(motornum)
    for pin in steppins:
        GPIO.setup(pin,GPIO.OUT)
        GPIO.output(pin, False)
    return

def stepper_off():
    return [ 0, 0, 0, 0 ]

def set_stepper_drive(motornum, stepdata):
    steppins  = stepper_pins(motornum)
    for pin in range(len(steppins)):
        iopin = steppins[pin]
        if stepdata[pin] != 0:
            # print( f"Enable GPIO {iopin}" )
            GPIO.output(iopin, True)
            pass
        else:
            # print( f"Disable GPIO {iopin}" )
            GPIO.output(iopin, False)
            pass
    return

def main_loop():
    # The interval between slowing down the stepper motor styeps by 0.1ms is 
    # calculated as follows:
    #
    # Tape spool diameter at start: 44mm, at end: 69mm (measured)
    # Total number of steps to read tape: 238K (measured)
    # Initial speed: 3ms between steps (setting seems to work)
    # End speed: 44/69*3ms = 4.7ms between steps, for constant tape speed
    # Number of 0.1ms increments in wait between at steps start and end: 17
    # Number of steps between increments: 238K/17 = 14K = "slowrate" below

    waittime  = 0.0030      # 3.0ms wait between steps (initial)
    waitstep  = 0.0005      # 0.5ms wait increment     (k/b change)
    slowrate  = 14000       # Interval (steps) between increase of stepper wait by 0.1ms
    slowcount = slowrate    # Steps to next speed reduction

    running   = False       # Start with motor stopped
    stepnum   = 0           # Step sequence number
    stepdir   = 1           # +1 forward, -1 backward (or +2, -2?)
    debugging = False       # Debug display enabled
    steptotal = 0           # Count total number of steps

    print("Control options:")
    print("  r         Run/resume motion")
    print("  s         Stop motion")
    print("  f         Move forwards")
    print("  b         Move backwards")
    print("  > or .    Go faster")
    print("  < or ,    Go slower")
    print("  d         Debug display on")
    print("  x         Debug display off")
    print("  q         Stop movement and exit")

    stepper_init(0)

    while True:
        # Test for keypress
        c = get_stdin_char()
        if c:
            print(f"Entered '{c}'")
            if c == "q":
                break
            elif c in ">.":
                waittime -= waitstep    # Faster: reduce waittime
                if waittime < waitstep:
                    waittime = waitstep
            elif c in "<,":
                waittime += waitstep    # Slower: increase waittime
            elif c == "s":
                running = False         # Pause
            elif c == "r":
                running = True          # Resume
            elif c == "f":
                stepdir = +1            # Direction forwards
            elif c == "b":
                stepdir = -1            # Direction backwards
            elif c == "d":
                debugging = True
            elif c == "x":
                debugging = False
            elif c == " ":
                pass
            else:
                print(f"Unrecognized '{c}'\n")
            print(f"steptotal {steptotal:>8d}, waittime {waittime:6.4f}, slowcount {slowcount:>6d}, stepdir {stepdir}, stepnum {stepnum}")
        # Next step
        if running:
            stepnum, stepdata = next_step(stepnum, stepdir)
            # drive stepper motor
            set_stepper_drive(0, stepdata)
            steptotal += 1
            if debugging:
                print(f"steptotal {steptotal:>8d}, waittime {waittime:6.4f}, slowcount {slowcount:>6d}, stepdir {stepdir}, stepnum {stepnum}")
        # Wait before moving on
        # Every "slowrate" steps, increase stepper wait interval by 0.1ms, to compensate for
        # increased diameter of tape on take-up spool.  Without this, the tape speed increases
        # and frames may become merged.
        time.sleep(waittime)
        slowcount -= 1
        if slowcount <= 0:
            waittime += 0.0001                  # Increase wait between steps by 0.1ms
            slowcount = slowrate                # Reset counter to next slowdown point
            print(f"steptotal {steptotal:>8d}, waittime {waittime:6.4f}")

    print("Exiting")
    set_stepper_drive(0, stepper_off())

# Print instruction summary
main_loop()
# Print exit summary

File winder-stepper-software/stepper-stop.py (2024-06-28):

#!/usr/bin/python
# Import required libraries
import sys
import time
import RPi.GPIO as GPIO

# PiStep2 pins to use:
#
# Physical pins 11, 12, 13, 15 for Motor A (GPIO 17, 18, 27, 22)
# Physical pins 7, 22, 18. 16 for Motor B (GPIO 4, 25, 24, 23)
# Physical pins 33, 32, 31, 29 for Motor C (GPIO 13,12,6,5)
# Physical Pins 38, 37, 36, 35 for Motor D (GPIO 20,26,16,19)


# Use BCM GPIO references
# instead of physical pin numbers
GPIO.setmode(GPIO.BCM)

# Define GPIO signals to use
# Physical pins 11,12,13,15  -- motor A on Pistep 2 hat
StepPins = [17,18,27,22]

# Set all pins as output
for pin in StepPins:
  print("Setup pins")
  GPIO.setup(pin,GPIO.OUT)
  GPIO.output(pin, False)

# Define advanced sequence
# as shown in manufacturers datasheet
Seq = [[1,0,0,1],
       [1,0,0,0],
       [1,1,0,0],
       [0,1,0,0],
       [0,1,1,0],
       [0,0,1,0],
       [0,0,1,1],
       [0,0,0,1]]

StepCount = len(Seq)
StepDir = 1 # Set to 1 or 2 for clockwise
            # Set to -1 or -2 for anti-clockwise
Stop = [0,0,0,0]

# Read wait time from command line
if len(sys.argv)>1:
  WaitTime = int(sys.argv[1])/float(1000)
else:
  WaitTime = 10/float(1000)

# Initialise variables
StepCounter = 0
WaitTime    = 0.01

# Start main loop
while False:

  #print( StepCounter, )
  #print( Seq[StepCounter] )

  for pin in range(0, 4):
    xpin = StepPins[pin]#
    if Seq[StepCounter][pin]!=0:
      print( " Enable GPIO %i" %(xpin) )
      GPIO.output(xpin, True)
    else:
      GPIO.output(xpin, False)

  StepCounter += StepDir

  # If we reach the end of the sequence
  # start again
  if (StepCounter>=StepCount):
    StepCounter = 0
  if (StepCounter<0):
    StepCounter = StepCount+StepDir

  # Wait before moving on
  time.sleep(WaitTime)

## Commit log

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2021-09-06 Fixed reader bar support shape; added spool winder spacer
    [monotype-tape-spool-readerbar.stl, monotype-tape-spool-winder-spacer.stl, monotype-tape-spool.scad]
2021-09-09 Added Makefile and start beaking design into modules
    [monotype-tape-reader-defs.scad, monotype-tape-reader-winder.scad, monotype-tape-reader.scad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]
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2021-09-16 Add config; rename files to fit on printer display
    [reader-bridge.scad, reader-camholder.scad, reader-common.scad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]
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2021-09-18 Fix error in camera support definition
    [monotype-tape-reader.scad]
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2021-09-24 Add mounting point and alternative mounting plate for camera holder
    [reader-baseplate.scad, reader-camholder.scad, reader-common.scad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]
2021-09-24 Fix up mounting hole locations
    [reader-baseplate.scad]
2021-09-25 Tweak baseplate dimensions; camera holder changes; baseplate holes still wrong
    [reader-baseplate.scad, reader-camholder.scad, reader-defs.scad]
2021-09-26 Adjust mounting plate width in baseplate, to match winder supports, etc.
    [reader-baseplate.scad, reader-common.scad]
2021-09-27 Adjust M4 hole size for clearance; refactoring
    [reader-baseplate.scad, reader-common.scad, reader-defs.scad]
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2021-09-30 Tweak baseplate domensions to better accommodate camera mounting
    [reader-baseplate.scad, reader-baseplate.stl, reader-defs.scad]
2021-09-30 Attempt at revised camera holder fixing plate
    [phone_holder_rod_fixing_plate.stl, reader-camholder.scad, reader-common.scad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]
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2021-10-09 Add taper to nut recess to give it a better chance of printing cleanly.
    [crank_handle.stl, reader-common.scad]
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2021-10-10 Add slot to winder supports to allow spool to be lifted out.
    [reader-common.scad, reader-winder.scad, winder_side_support_slotted.stl]
2021-10-10 Winder side - add slot to allow shaft retaining lug to flex more easily. Initial C-clip desiogn for holding tape on spool.
    [reader-common.scad, reader-defs.scad, reader-winder.scad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]
2021-10-10 Add second flex slot is winder side support; increase length of slots.
    [reader-common.scad, reader-defs.scad, reader-winder.scad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]
2021-10-11 Add tape guides and tensioner bars to reader bridge
    [reader-bridge.scad, reader-common.scad, reader-defs.scad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]
2021-10-11 Adjust parameters for tensioner bars on reader bridge; enlarge holes for threading EL wire.
    [reader-bridge.scad, reader-common.scad, reader-defs.scad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]
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2022-06-27 Journal updates; DHOxSS poster; enlarged reader baseplate in two parts
    [reader-baseplate.scad, reader-baseplate_1.stl, reader-baseplate_2.stl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]
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2022-06-28 Reader bar mods: reduce depth of EL wire slot; add hole for crank shaft
    [reader-bridge.scad, reader-bridge.stl, reader-common.scad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]
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2022-06-28 Rework reader bridge layout for easier fit on priunter bed
    [reader-bridge.scad, reader-bridge.stl, tape_reader_bridge_dovetailed.stl]
2022-06-29 Revised design for spool clip, partly to overcome printing problem
    [reader-common.scad, reader-winder.scad, spool_clips.stl]
2022-06-30 Tweak winder side support - trying to make it easier to push in winder
    [reader-common.scad, reader-winder.scad, winder_side_support_slotted.stl]
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2022-08-19 Review Mk2 reader design; considering changes for Mk3; work-in-progress
    [reader-common.scad, reader-winder.scad]
2022-08-22 Toward designs for spoked sprocket for tape guide
    [reader-common.scad, test_sprocket.stl]
2022-08-22 Factor out 'common-components', test design for sprocketed tape guide.
    [common-components.scad, reader-common.scad, tape_guide.stl]
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2022-08-23 Tweak position/size of cutout in tape guide roller
    [common-components.scad, tape_guide.stl]
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2022-09-10 Tweak plug parameters (was too tight)
    [common-components.scad, test_bayonette_plug.stl]
2022-09-10 Tweak plug parameters (still too tight)
    [common-components.scad, test_bayonette_plug.stl]
2022-09-11 Use channel constriction for final 'click' (depth too fussy to get right)
    [common-components.scad, test_bayonette_pair.stl, test_bayonette_plug.stl]
2022-09-11 Tweak plug parameters (tighter fit)
    [common-components.scad, test_bayonette_plug.stl]
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2022-09-14 Revised tape spool clip with anti-slip ridge
    [reader-winder.scad, tape-spool-clip.stl]
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2022-09-15 Monor rework tape spool and clip design
    [common-components.scad, reader-winder.scad, spool_clips.stl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]
2022-09-15 Adjust rim of tape clip - ensure extra width for adhesion survives slicing
    [reader-winder.scad, tape-spool-clip.stl]
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2022-09-28 Add middle support hub for spool; tweak side supports
    [reader-winder.scad, spool_middle_hub.stl, winder_side_supports.stl]
2022-09-28 Fix dimension error in spool middle hub
    [reader-winder.scad, spool_middle_hub.stl]
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2022-10-02 Storage spool clip closed and more clearance for sliding on/off spool
    [reader-defs.scad, reader-winder.scad, spool_clip.stl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]
2022-10-03 Increase storage spool clip clearance
    [reader-winder.scad, spool_clip_closed.stl]
2022-10-03 Redesign spool support to also support winder crank (avoids drive-belt stress on assembbly)
    [common-components.scad, reader-winder.scad, spool_and_winder_side_support.stl]
2022-10-03 Adjust spool clip design foir (hopefully) cleaner printing
    [reader-winder-obsolete.scad, spool_clip_closed.stl]
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2022-10-05 Fix bug in spool_and_winder_side_support
    [common-components.scad, reader-winder.scad, spool_and_winder_side_support.stl]
2022-10-05 Extra paramneterization; extend thickness of crank hub to clear drive pulley
    [common-components.scad, crank_handle.stl, reader-defs.scad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]
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2022-10-05 Tune design of sprocketed tape guide: larger pins + rims
    [common-components.scad, reader-bridge.scad, reader-defs.scad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]
2022-10-06 Tweak sprocket spacing - tape was riding up on sprockets
    [common-components.scad, reader-bridge.scad, reader-defs.scad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]
2022-10-07 Add support for tape guide roller in reader bridge
    [read_side_support_dovetailed.stl, reader-bridge.scad]
2022-10-07 Add tape guide roller, shaft supports in side, tweak dimensions
    [read_side_support_dovetailed.stl, reader-bridge.scad, roller_tape_guide.stl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]
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2022-10-07 Testing different design for shaft nut carrier: add nut ejection hole
    [reader-bridge.scad, test_shaft_nut_carrier.stl]
2022-10-08 Improve design for shaft nut holder in tape guides
    [common-components.scad, reader-bridge.scad, roller_tape_guide.stl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]
2022-11-22 Work in progress: design for stepper motoir drive
    [common-components.scad, reader-defs.scad, reader-winder.scad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]
2022-11-22 Add mounting bracket and pulley for stepper motor
    [reader-winder.scad, reader-winder.stl, test-reader-winder.stl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]
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2022-12-10 Rework stepper motor bracket mounting
    [reader-defs.scad, reader-winder.scad, stepper_bracket_and_sleeve.stl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]
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2022-12-10 Fix sleeve to clamp bracket onto spool holder arm
    [reader-winder.scad, stepper_bracket_sleeve.stl]
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2022-12-18 Shorter baseplate; add recessed nut holders
    [reader-baseplate.scad, reader-defs.scad, reader_half_baseplate_1.stl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]
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2023-01-29 Stiffen up stepper motor support
    [reader-winder.scad, spool_and_motor_side_support_R.stl]
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2023-02-04 Adjust reader bridge side supports for roller rim clearance
    [read_side_support_dovetailed_2off.stl, reader-bridge.scad]
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2023-02-11 Nylock nut recess cutout in roller guide; increase nylock support ledge width
    [common-components.scad, reader-bridge.scad, roller_tape_guide.stl]
2023-02-12 Redesign spool clip
    [common-components.scad, reader-winder.scad, spool_clip_closed.stl]
2023-02-13 Rework spool slip for greater stability while printing
    [reader-winder.scad, spool_clip_closed.stl]
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2023-02-17 Rework pulley design with U channel; add shim for spool end
    [common-components.scad, crank_handle.stl, drive_pulley.stl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]
2023-02-19 Reinstate tape spool cutaway support (doesn't print well without)
    [reader-winder.scad, reader-winder_50.stl, spool_clip_closed.stl]
2023-02-19 Wider/deeper stepper pulley, so extra band doesn't pop off
    [crank_handle.stl, reader-winder.scad, stepper_pulley_35.stl]
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2023-02-21 Redesign phone holder clamp; refactor phone holder code
    [phone_camera_holder_2off.stl, reader-camholder.scad, reader-common.scad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]
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2023-03-03 Make pushon crank thinner, to fit on short shaft
    [crank_handle_pushon.stl, reader-winder.scad]
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2023-03-03 Deeper nut recess in rewind pulley, to fit on short shaft
    [reader-winder.scad, rewind_pulley.stl]
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2023-03-24 Add short tape follower arm design.
    [reader-bridge.scad, tape_follower_short_arm_2off.stl]
2023-03-24 Remove file in wrong place
    [tape_follower_roller.stl]
2023-04-16 Adjust and fix feed spool support - hopefully will turn more freely
    [reader-winder.scad, reader-winder.stl]
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2023-05-26 Make tape follower short arms cranked, less sloppy
    [reader-bridge.scad, tape_follower_short_arm_4off.stl]
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2023-11-19 Baseplate mods to moive camera supports away for more clearance. Tape follower short arms rendered (are these still needed?). Redesign bridge for new EL wire, wider light baffles at ends.
    [baseplate_clamp.stl, half_spool-2off.stl, phone_holder_rod_anti_rotation_plate.stl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]
2023-11-21 Update designs for camera hol;der;, add new plate to allow more adjustment.
    [phone_holder_rod_adjusting_plate.stl, reader-bridge.scad, reader-camholder.scad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]
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2023-12-28 Tape spool and motor holder sides with M6 shaft slots; thicker clip pieces
    [reader-winder.scad, spool_and_swivel_mount_side_support_m6.stl, spool_side_support_slotted_m6.stl]
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2023-12-30 Increase hinge clearances on side support
    [common-components.scad, reader-winder.scad, spool_and_swivel_mount_side_support_m6.stl]
2024-01-06 Adjust reader bridge to use bearing sleeves; increase height; shorten tape follower arm. Add designs for some simple reader assembly tools.
    [common-components.scad, reader-bridge-side-supports-and-follower-arms_m6.stl, reader-bridge.scad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]
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2024-01-12 New parts for mounting Raspberry {i zero (and other electronics) Update tape follower arms and tape followers to use sleeve bearings Update reader bridge shape to clear side pieces New tool for tight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
    [common-components.scad, nut_spinner_tool_m4.stl, reader-bridge.scad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]
2024-01-12 Tweak nut spinner tools. Revise design of outer light shade on reader bridge to be printable.
    [nut_spinner_tool_m4.stl, nut_spinner_tools.stl, reader-bridge.scad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]
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2024-01-18 Redesign reder brtidge side with separate follower pivot arm support
    [common-components.scad, reader-bridge.scad, reader-defs.scad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]
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2024-06-30 Rework assembly and exploded views
    [Monocaster-assembly-exploded.stl, reader-assembly.scad]
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2024-09-23 Make baseplate 2mm wider for greater spool and roller end clearance
    [reader-baseplate.scad, reader-defs.scad, reader_half_baseplate_1.stl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]
2024-10-19 Tweak designs for printing with PETG. Add hub strength in roller tape follower. Some refactoring. Maybe other changes.
    [common-components.scad, cutaway_roller.stl, monoscope_parts.stl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]
2024-10-20 Add clearance to nut cutout so that the shaft (hopefully) doesn't get pushed off-axis.
    [common-components.scad, reader-bridge.scad]
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2024-11-11 Winder spool redesign with bearing lugs so it twists on more easily. Winder spool ends with thicker spoikes to be less fragile. Fix up some comments. Refresh generated STL files.
    [common-components.scad, phone_holder_rod_support.stl, reader-baseplate.scad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]
